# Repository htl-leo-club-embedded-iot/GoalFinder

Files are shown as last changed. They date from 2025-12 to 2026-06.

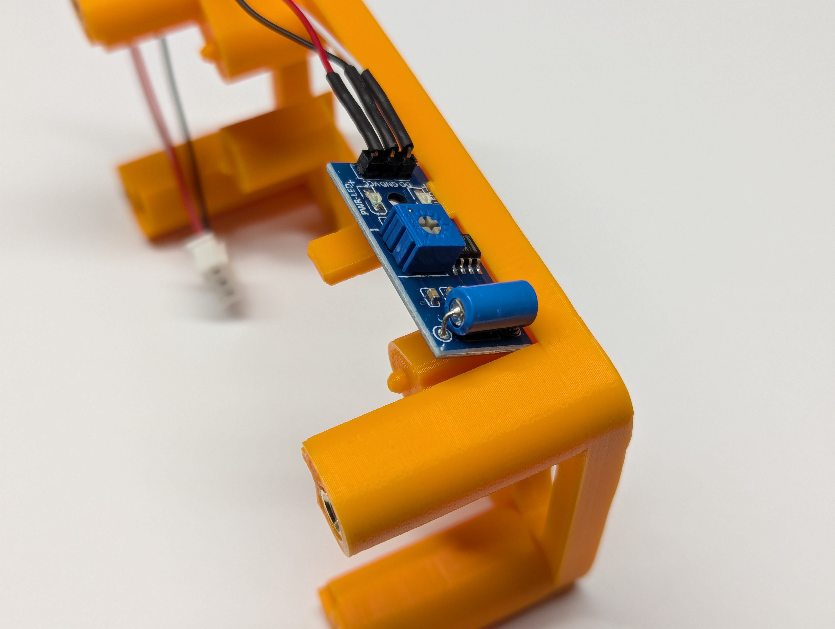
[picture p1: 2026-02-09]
docs/images/fotodoc_assemby/orig/PXL_20251103_211330798.jpg

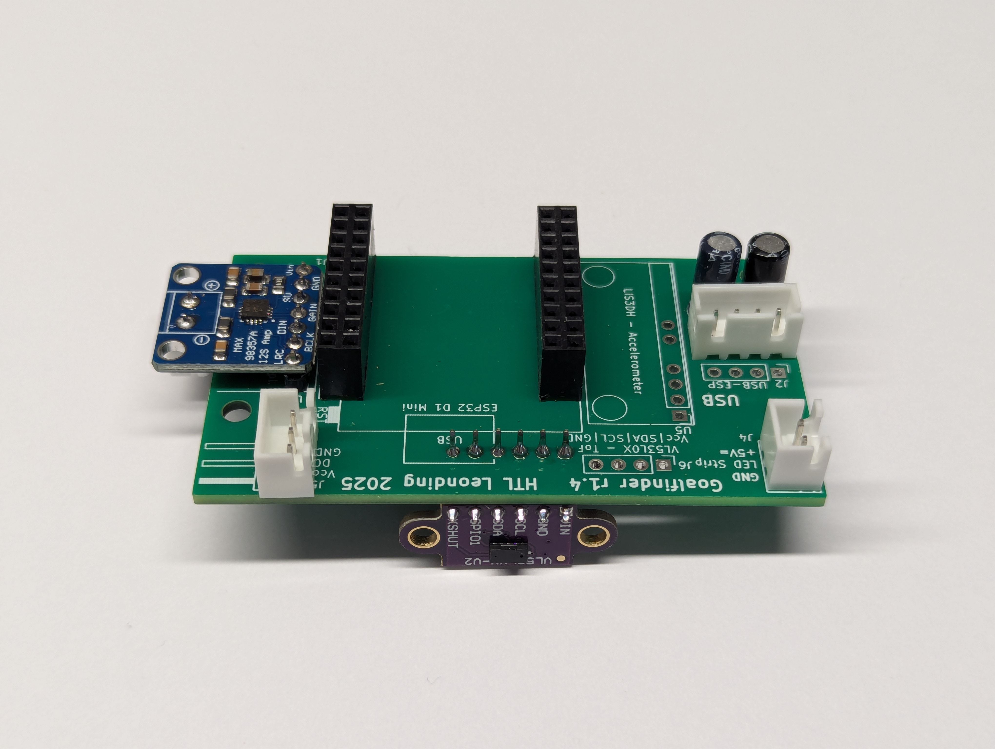
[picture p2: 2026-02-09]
docs/images/fotodoc_assemby/orig/PXL_20251103_104626845.jpg

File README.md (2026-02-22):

# Goalfinder

## About

The GoalFinder device aims to help blind or visually impaired people play basketball by playing a sound to help locate the basket and provides acoustic and visual feedback on hits and misses.
For more information, please visit the [GoalFinder Website](https://goalfinder.github.io)

## Branches

### Main Branches

+ `main` The main branch is used for releases only
+ `development` Is the branch that sees all development work

### Backup Branches

There are still two discontinued branches from before the takeover

+ `pages-alt` Old GitHub Pages branch
+ `multithreading-alt` Old branch focused on adding multithreading to the GoalFinder device

## Website

The GoalFinder website is accessible at [goalfinder.github.io](https://goalfinder.github.io) and is split of into [it's own repository](https://github.com/goalfinder/goalfinder.github.io)

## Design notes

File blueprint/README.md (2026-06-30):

# Blueprint Directory

## Structure
    .
    ├── design          The development section for the GoalFinder device
    │   ├── housing/        The design for the housing
    │   └── pcb/            The design for the PCB
    └── export          To be exported files for production
        ├── 3d-files/       .3mf projects or .gcode (mostly for Creality K1C and K1 Max printers using Hyper-PLA) files for producing the housing
        └── pcb/            Generated production files for producing the PCB

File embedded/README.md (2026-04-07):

# Embedded Directory

## Testing And Coverage

The test setup uses a dedicated host environment (`env:native`) in
`platformio.ini`. Tests are compiled and executed on the CI runner and are
never included in the firmware image built for `wemos_d1_mini32`.

Run tests locally:

```bash
pio test -e native
```

Generate function coverage for project sources:

```bash
gcovr --root . --object-directory .pio/build/native --filter src --filter lib --txt --txt-metric function
```

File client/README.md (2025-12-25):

# Client Directory

## Structure

    .
    ├── .gitignore           Git ignore rules for the client directory
    ├── merge-bin.py         Python script for merging binary files
    ├── platformio.ini       PlatformIO configuration file
    ├── data/                Data files for the firmware
    │   └── web/             Web assets for the firmware
    │       └── assets/      CSS files for web views
    │           ├── GamesView.css
    │           ├── GeneralSettingsView.css
    │           └── NotFoundView.css
    ├── lib/                Libraries used in the firmware
    │   ├── file_system/    File system management library
    │   │   ├── FileSystem.cpp
    │   │   └── FileSystem.h
    │   ├── lib_audioplayer/    Audio player library
    │   │   ├── library.json
    │   │   ├── include/
    │   │   │   └── AudioPlayer.h
    │   │   └── src/
    │   │       └── AudioPlayer.cpp
    │   ├── lib_bluetoothmanager/   Bluetooth manager library
    │   │   ├── library.json
    │   │   ├── include/
    │   │   │   └── BluetoothManager.h
    │   │   └── src/
    │   │       └── BluetoothManager.cpp
    │   ├── lib_settings/    # Settings management library
    │   │   ├── hal_selector.py
    │   │   ├── library.json
    │   │   ├── include/
    │   │   │   └── system/
    │   │   │       └── Settings.h
    │   │   └── src/
    │   │       └── hal/
    │   │           └── system/
    │   │               ├── dummy/
    │   │               │   └── DummySettings.cpp
    │   │               ├── esp32/
    │   │               │   └── Esp32Settings.cpp
    │   │               └── esp8266/
    │   │                   └── Esp8266Settings.cpp
    │   ├── lib_tofsensor/   Time-of-flight sensor library
    │   │   ├── library.json
    │   │   ├── include/
    │   │   │   └── ToFSensor.h
    │   │   └── src/
    │   │       └── ToFSensor.cpp
    │   └── lib_vibrationsensor/    Vibration sensor library
    │       ├── library.json
    │       ├── include/
    │       │   └── VibrationSensor.h
    │       └── src/
    │           └── VibrationSensor.cpp
    ├── src/    Main application source code
    │   ├── GoalfinderApp.cpp
    │   ├── GoalfinderApp.h
    │   ├── LedController.cpp
    │   ├── LedController.h
    │   ├── LedMode.h
    │   ├── main.cpp    Entry point of the firmware
    │   ├── Settings.cpp
    │   ├── Settings.h
    │   ├── Singleton.h
    │   └── web/             # Web-related source code
    │       ├── SNTP.cpp
    │       ├── SNTP.h
    │       ├── SoftwareUpdater.cpp
    │       ├── SoftwareUpdater.h
    │       ├── WebServer.cpp
    │       ├── WebServer.h
    │       ├── WifiManager.cpp
    │       └── WifiManager.h

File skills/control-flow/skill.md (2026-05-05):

---
name: Control Flow
---

# Control Flow Skill

## Core Philosophy

**Goal**: Ensure execution flow is predictable, testable, and deterministic. Restrict patterns that make reasoning about code behavior difficult.

## Return Statement Rules

### Mandatory Constraints

- **Functions returning values MUST have exactly ONE return statement**
- **Early returns are strictly forbidden**
- **Void functions MUST NOT use any return statement**

### Rationale

Single return points make code behavior predictable and testable:
- Easier to trace execution paths
- Simpler to add cleanup logic
- Better support for debugging and profiling
- Follows principles used in safety-critical systems

### Examples

**Standard - Single Return Pattern:**

```typescript
function validateUser(user: User): boolean {
  let isValid = false;
  
  if (user.id && user.email && user.role) {
    if (user.email.includes('@')) {
      isValid = true;
    }
  }
  
  return isValid;
}
```

**Standard - Void Function (No Return):**

```cpp
void logEvent(const Event& event) {
  if (isEnabled()) {
    Logger::write(event.toString());
  }
}
```

## Loop and Flow Restrictions

### Forbidden Constructs

- **`goto` is strictly forbidden** - Unconditional jumps make code flow unpredictable
- **`break` outside `switch` statements is forbidden** - Use flags or restructure loops instead
- **`continue` should be avoided** - Restructure logic instead; only use with explicit justification in comments

### Rationale

These constructs create non-local jumps in execution flow that:
- Make it difficult to reason about code behavior
- Complicate static analysis and testing
- Can obscure resource cleanup paths
- Violate structured programming principles

### Examples

**Standard - Loop with Flag Variable:**

```cpp
size_t foundIndex = -1;
bool found = false;

for (size_t i = 0; i < data.size() && !found; ++i) {
  if (data[i] == target) {
    foundIndex = i;
    found = true;
  }
}
```

**Standard - Inverted Logic:**

```typescript
for (let user of users) {
  if (user.active) {
    processUser(user);
  }
}
```

## Preferred Control Flow Structure

### Linear, Sequential Logic

Structure code in clear, sequential blocks that flow from top to bottom:

```typescript
function processConnection(config: Config): Result {
  let result: Result = { success: false };
  
  // Step 1: Validate input
  const isValidConfig = validateConfig(config);
  
  // Step 2: Establish connection
  let connection: Connection | null = null;
  if (isValidConfig) {
    connection = establishConnection(config);
  }
  
  // Step 3: Perform operations
  let operationSuccess = false;
  if (connection !== null) {
    operationSuccess = performOperations(connection);
  }
  
  // Step 4: Cleanup and prepare result
  if (connection !== null) {
    closeConnection(connection);
  }
  
  result.success = isValidConfig && operationSuccess;
  
  return result;
}
```

### State-Based Flow (When Appropriate)

Use state variables and state machines for complex flows:

```cpp
enum class ConnectionState {
  IDLE,
  CONNECTING,
  CONNECTED,
  ERROR,
  CLOSED
};

class Connection {
private:
  ConnectionState _state = ConnectionState::IDLE;
  
public:
  void handleEvent(const Event& event) {
    switch (_state) {
      case ConnectionState::IDLE:
        if (event.type == EventType::CONNECT) {
          _state = ConnectionState::CONNECTING;
        }
        break;
      case ConnectionState::CONNECTING:
        if (event.type == EventType::SUCCESS) {
          _state = ConnectionState::CONNECTED;
        } else if (event.type == EventType::FAILURE) {
          _state = ConnectionState::ERROR;
        }
        break;
      // ... other states
    }
  }
};
```

### Switch Statements

Switch statements are acceptable for handling discrete options:

```typescript
function handleMessage(type: MessageType, data: any) {
  switch (type) {
    case MessageType.CONNECT:
      establishConnection(data);
      break;
    case MessageType.DISCONNECT:
      closeConnection();
      break;
    case MessageType.DATA:
      processData(data);
      break;
    default:
      logUnknownMessage(type);
  }
}
```

## Mandatory Exceptions

### Break in Switch Statements

`break` is **required** in switch statements to prevent fall-through:

```typescript
switch (event) {
  case 'click':
    handleClick();
    break;
  case 'hover':
    handleHover();
    break;
}
```

## Benefits of These Rules

✓ **Testability**: Single execution paths are easier to test  
✓ **Debugging**: Call stacks are predictable and traceable  
✓ **Maintainability**: Code changes have localized impact  
✓ **Performance**: No unpredictable jumps affecting branch prediction  
✓ **Safety**: Follows practices from safety-critical system standards  
✓ **Clarity**: Control flow is immediately obvious on code review  

## Review Checklist

When reviewing control flow compliance:

- [ ] No early returns in non-void functions
- [ ] No `goto` statements
- [ ] No `break` outside switch statements
- [ ] `continue` is justified (if present) with a comment
- [ ] Void functions do not have unnecessary returns
- [ ] Execution flow is linear and predictable
- [ ] State machines used where appropriate for complex logic
- [ ] Loop exit conditions are clear
- [ ] Exception handling (if used) doesn't create hidden control flow

## Migration Guide

If working with legacy code that violates these rules, prioritize refactoring:

1. **High priority**: Remove all `goto` statements
2. **High priority**: Consolidate multiple return statements
3. **Medium priority**: Replace `break` in loops with state flags
4. **Medium priority**: Restructure `continue` patterns
5. **Low priority**: Clean up other control flow patterns

Document exceptions in code review comments and create follow-up tasks for refactoring.

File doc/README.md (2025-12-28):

# Documentation

This directory contains the GoalFinder project's technical documentation and contribution guidance.

## Project structure

    ..
    ├── github              GitHub workflows for CI/CD
    ├── .vscode             Configuration files for Visual Studio Code
    ├── assets              Assets for development and documentation
    ├── blueprint           Hardware design files, including 3D models and PCB layouts
    ├── client              Software for the Goalfinder Board, including firmware
    ├── doc-alt             Documentation from the previous repository
    ├── .gitignore          Files and directories excluded from git source control
    ├── LICENSE             Licensing information for the project
    ├── package-lock.json   Locked npm dependencies for consistent builds
    └── README.md           Description of the repository

## Contribute

See the [contribution guide](./contribute/README.md) for detailed instructions on how to use the provided development tools.

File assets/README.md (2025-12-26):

# Assets Directory

## Structure
    .
    ├── audio               Audio files
    │   ├── beep                Beep Sounds
    │   ├── goal                Goal sounds
    │   ├── metronome           Metronome Sounds
    │   ├── miss                Miss sounds
    │   └── success             Success sounds
    └── img                 Image files
        └── logo                Logos

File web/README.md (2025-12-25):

# Web Directory

This template should help get you started developing with Vue 3 in Vite.

## Recommended IDE Setup

[VSCode](https://code.visualstudio.com/) + [Volar](https://marketplace.visualstudio.com/items?itemName=Vue.volar) (and disable Vetur).

## Type Support for `.vue` Imports in TS

TypeScript cannot handle type information for `.vue` imports by default, so we replace the `tsc` CLI with `vue-tsc` for type checking. In editors, we need [Volar](https://marketplace.visualstudio.com/items?itemName=Vue.volar) to make the TypeScript language service aware of `.vue` types.

## Customize configuration

See [Vite Configuration Reference](https://vite.dev/config/).

## Project Setup

```sh
npm install
```

### Compile and Hot-Reload for Development

```sh
npm run dev
```

### Type-Check, Compile and Minify for Production

```sh
npm run build
```

## Structure

    .
    ├── .gitignore           # Git ignore rules for the web directory
    ├── env.d.ts             # TypeScript environment variable definitions
    ├── index.html           # Entry point for the web application
    ├── package.json         # npm configuration file for managing dependencies
    ├── README.md            # Documentation for the web directory
    ├── tsconfig.app.json    # TypeScript configuration for the application
    ├── tsconfig.json        # Base TypeScript configuration
    ├── tsconfig.node.json   # TypeScript configuration for Node.js scripts
    ├── vite.config.ts       # Vite configuration file for development and build
    ├── src/                 # Source code for the web application
    │   ├── App.vue          # Root Vue component
    │   ├── main.ts          # Entry point for the application
    │   ├── assets/          # Static assets such as styles and images
    │   │   ├── main.css     # Global CSS styles
    │   │   └── logos/       # Logo images
    │   ├── components/      # Reusable Vue components
    │   │   ├── BluetoothManager.vue
    │   │   ├── Button.vue
    │   │   ├── Card.vue
    │   │   ├── IconButton.vue
    │   │   ├── InputForm.vue
    │   │   ├── LaserSensorManager.vue
    │   │   ├── LedManager.vue
    │   │   ├── Modal.vue
    │   │   ├── NavigationBar.vue
    │   │   ├── Page.vue
    │   │   ├── SoftwareUpdateModal.vue
    │   │   ├── ToggleButton.vue
    │   │   ├── VibratiosensorManager.vue
    │   │   └── VolumeManager.vue
    │   │   └── icons/       # Icon components
    │   │       ├── AddIcon.vue
    │   │       ├── BluetoothIcon.vue
    │   │       ├── GearIcon.vue
    │   │       ├── InfoCircleIcon.vue
    │   │       ├── LightbulbIcon.vue
    │   │       ├── MinusIcon.vue
    │   │       ├── PlayIcon.vue
    │   │       ├── PowerIcon.vue
    │   │       ├── TrashIcon.vue
    │   │       ├── UpdateIcon.vue
    │   │       ├── VolumeUpIcon.vue
    │   │       └── WifiOffIcon.vue
    │   ├── models/          # TypeScript models for data structures
    │   │   ├── game.ts
    │   │   ├── player.ts
    │   │   └── team.ts
    │   ├── router/          # Vue Router configuration
    │   │   └── index.ts
    │   ├── stores/          # Pinia stores for state management
    │   │   ├── games.ts
    │   │   └── settings.ts
    │   └── views/           # Vue components for application views
    │       ├── AboutView.vue
    │       ├── HomeView.vue
    │       ├── NotFoundView.vue
    │       ├── Games/       # Game-related views
    │       │   ├── GamesView.vue
    │       │   ├── ShotChallengeView.vue
    │       │   └── TimedShotsChallengeView.vue
    │       └── Settings/    # Settings-related views
    │           ├── AudioSettingsView.vue
    │           ├── DevicesSettingsView.vue
    │           ├── SettingsView.vue
    │           └── SystemSettingsView.vue

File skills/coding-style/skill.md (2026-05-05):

---
name: Coding Style
--- 

# Coding Style Skill

## Core Principles

- **Minimal implementations**: Favor simplicity and directness over clever constructs
- **Code reuse**: Leverage existing infrastructure whenever possible
- **Avoid duplication**: Unnecessary abstraction should be eliminated
- **Prioritize readability**: Never sacrifice clarity for brevity

## Naming Conventions

### General Rules

- Use clear and meaningful variable names that self-document their purpose
- Avoid cryptic abbreviations unless they are widely understood in the specific context
- Names should reflect intent and domain terminology

### Language-Specific Conventions

#### TypeScript / JavaScript

- **Constants**: `UPPER_SNAKE_CASE` (e.g., `MAX_RETRIES`)
- **Variables & Functions**: `camelCase` (e.g., `connectionStatus`, `handleClick()`)
- **Classes & Interfaces**: `PascalCase` (e.g., `ConnectionManager`, `ISettings`)
- **Private members**: Prefix with underscore `_privateMethod()`
- **Vue components**: `PascalCase` with `.vue` extension (e.g., `ConnectionSettingsView.vue`)

#### C++

- **Constants & Macros**: `UPPER_SNAKE_CASE` (e.g., `MAX_BUFFER_SIZE`)
- **Functions**: `camelCase` or `PascalCase` depending on context (e.g., `handleEvent()`, `ProcessData()`)
- **Classes**: `PascalCase` (e.g., `LedController`)
- **Member variables**: Prefix with underscore `_memberVar`
- **Private methods**: Prefix with underscore `_privateMethod()`

## Code Structure

### Function Organization

- **Keep functions small and focused**: Each function should have a single, clear responsibility
- **Single level of abstraction**: Functions should operate at one conceptual level
- **Prefer straightforward logic**: Avoid clever or complex constructs that reduce readability

### File Organization

- **Group related functionality**: Keep related code in the same file or module
- **Logical ordering**: Define utilities before usage, public interfaces before implementations
- **Clear separation of concerns**: Different concerns should be in different files

## Line Length & Formatting

- **Target line length**: 100 characters maximum
- **Respect language conventions**: Follow language-specific style guides (Prettier for TS/JS, clang-format for C++)
- **Indentation**: Use consistent indentation (2 spaces for YAML/JSON, 4 spaces for code)

## Import Organization

### TypeScript/JavaScript

```typescript
// 1. External libraries
import Vue from 'vue'
import axios from 'axios'

// 2. Internal absolute imports
import { useStore } from '@/stores'
import { Logger } from '@/utils'

// 3. Relative imports
import { helper } from './helpers'
```

### C++

```cpp
// 1. System headers
#include <iostream>
#include <vector>

// 2. Library headers
#include <Arduino.h>

// 3. Local headers
#include "Config.h"
#include "LedController.h"
```

## Type Safety

- **Use types meaningfully**: Leverage language type systems to prevent errors
- **Avoid `any` in TypeScript**: Use proper typing; use `unknown` only when truly necessary
- **Be explicit**: Don't rely on implicit conversions

## Common Patterns

### Error Handling

- Use exceptions or result types consistently across the codebase
- Document error conditions in function documentation
- Avoid silent failures

### State Management

- Minimize mutable state
- Make state changes explicit and predictable
- Document state transitions when non-obvious

### Performance Considerations

- Write readable code first; optimize only where profiling shows bottlenecks
- Document performance-critical sections with explanatory comments
- Include benchmarks for critical paths if performance is important

## Review Checklist

When reviewing code for style compliance:

- [ ] Names clearly express intent
- [ ] Functions have single responsibility
- [ ] No unnecessary duplication
- [ ] Code is readable without extensive comments
- [ ] Language conventions are followed
- [ ] Import order is correct
- [ ] No overly complex control flow

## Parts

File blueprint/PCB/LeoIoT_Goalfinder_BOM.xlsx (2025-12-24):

Reference | Value | Footprint | Qty | Beschreibung | Comment / Supplier
C1 | 22µF | Capacitor_THT:CP_Radial_D5.0mm_P2.00mm | 1 | Polarized capacitor, small symbol
C2 | 4,7µF | Capacitor_THT:CP_Radial_D5.0mm_P2.00mm | 1 | Unpolarized capacitor, small symbol
C3 | 0,1µF | Capacitor_THT:C_Rect_L13.0mm_W4.0mm_P10.00mm_FKS3_FKP3_MKS4 | 1 | Unpolarized capacitor, small symbol
C4,C5,C6,C7,C8 | 100nF | Capacitor_SMD:C_0805_2012Metric_Pad1.18x1.45mm_HandSolder | 5 | Unpolarized capacitor, small symbol
Copt4,Copt5,Copt6,Copt7,Copt8 | 100nF | Capacitor_THT:C_Disc_D5.0mm_W2.5mm_P2.50mm | 0 | Unpolarized capacitor, small symbol | Optional for THT parts, replaces C4, C5, C6, C7, C8 https://www.reichelt.de/de/de/shop/produkt/keramik-kondensator_100_nf_-20_80_y5v_50_100_v_rm_5-9265
J2 | LED Strip | Connector_JST_2.54:JST_XH_B2B-XH-A_1x02_P2.54mm_Vertical | 1 | Connector for LED Strip
J1 | USB_B_Micro_Breakout | Breakout_Boards:Micro-USB_BreakoutBoard | 1 | USB Micro Type B connector | https://www.amazon.de/KARELLS-Steckerkabel-Verl%C3%A4ngerungskabel-Stromladekabel-Ersatzkabel/dp/B0D6362W88
D1, J1e1 | Conn_01x02_Pin | 5V LED Strip, max 30W | 1 | LED Strip with connector suitable for J2 | https://www.amazon.de/GOMING-COB-Selbstklebend-Wasserdicht-Lichtband/dp/B09VGR6PWH/ref=sr_1_4?th=1
J3 | GAIN | Connector_PinHeader_2.54mm:PinHeader_2x05_P2.54mm_Vertical | 1 | Jumper bar for gain selection | either wire bridge or:
 |  |  |  |  | Jumper: https://www.reichelt.de/de/de/shop/produkt/kurzschlussbruecke_schw_m_grifflasche-9019
 |  |  |  |  | Pin Header: https://www.reichelt.de/de/de/shop/produkt/stiftleiste_2x20-pol_vergoldet_2_54mm-235664
LS1 | Speaker | Breakout_Boards:Mono-Enclosed_Speaker_70x30x17mm_onboard | 1 | Speaker, 3 W, 8 Ohm | https://www.amazon.de/dp/B09PL6XFHC
Q1 | IRFZ44N | Package_TO_SOT_THT:TO-220-3_Horizontal_TabDown | 1 | FET | https://www.reichelt.de/de/de/shop/produkt/mosfet_n-ch_60v_48a_110w_0_023r_to220ab-257487
R1,R2 | 100k | Resistor_THT:R_Axial_DIN0309_L9.0mm_D3.2mm_P12.70mm_Horizontal | 2 | Resistor
R4 | 1k | Resistor_THT:R_Axial_DIN0309_L9.0mm_D3.2mm_P12.70mm_Horizontal | 1 | Resistor
R5 | 33k | Resistor_THT:R_Axial_DIN0309_L9.0mm_D3.2mm_P12.70mm_Horizontal | 1 | Resistor
U1 | ESP32_D1_mini | ESP32_D1_mini:ESP32_D1_mini | 1 | ESP32 D1 mini from AZ-Delivery | https://www.amazon.de/AZDelivery-Bluetooth-Internet-Entwicklungsboard-kompatibel/dp/B08BTYCGVV
U2 | VL53L0X_Breakout | Breakout_Boards:VL53L0X_Breakout_Board_vertical_flat | 1 | 2m distance ranging ToF sensor, Optical LGA12 | https://www.amazon.de/AZDelivery-VL53L0X-Flight-kompatibel-Arduino/dp/B086TSNTFD
U3 | MAX98357A_Breakout | Breakout_Boards:MAX98357A_Breakout_Board | 1 | Mono DAC with amplifier, I2S, PCM, TDM, 32-bit, 96khz, 3.2W, TQFP-16 | https://www.amazon.de/AZDelivery-filterloses-Breakout-Modul-Decoder-Modul-Anwendungsbereich/dp/B09PL947ZG
U4 | SW420_Breakout | Breakout_Boards:SW420_Breakout_Board_Horizontal | 1 | Vibrationsensor, Shocksensor | https://www.amazon.de/AZDelivery-Vibration-Sch%C3%BCttel-Ersch%C3%BCtterung-Arduino/dp/B07V9CZ89G

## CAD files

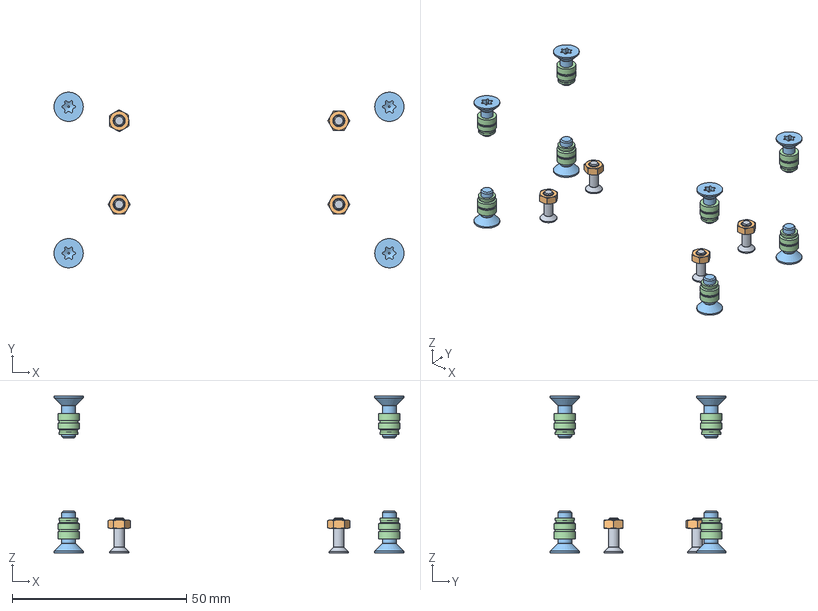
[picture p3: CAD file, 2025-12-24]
blueprint/Housing/LeoIoT-Goalfinder-Assembly_GF1_4_compact.FCStd
100.4 x 50.4 x 45.0 mm
M3x10-Schraube x 4
M3-Mutter x 4
M4x12-Schraube x 8
M4x6-Gewindeeinsatz x 8

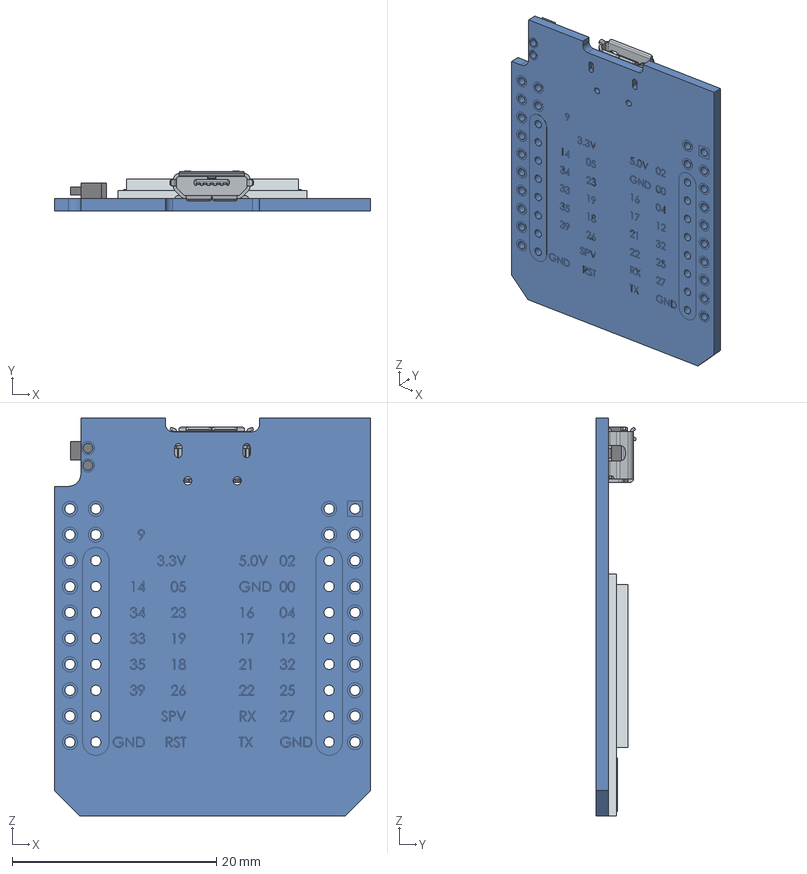
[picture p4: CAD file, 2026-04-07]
assets/3D/pcb/Wemos-Mini-D1-ESP32.STEP
31.0 x 3.92 x 39.0 mm
Wemos-Mini-D1-ESP32
Wemos-Mini-D1-ESP033
Wemos-Mini-D1-ESP034
Wemos-Mini-D1-ESP035

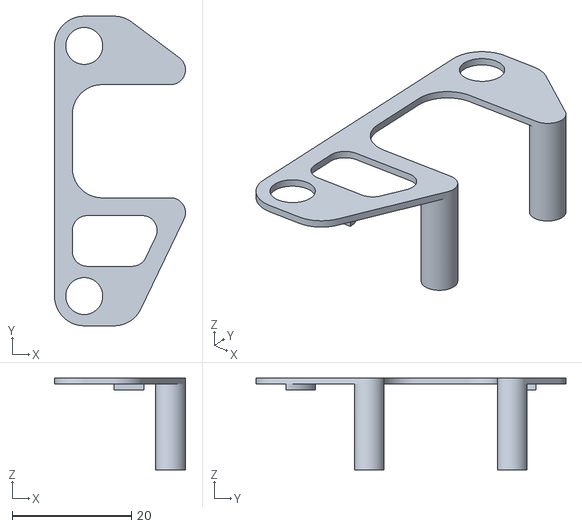
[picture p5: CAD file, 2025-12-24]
blueprint/Housing/3D-Print/bracket-top-left.stl
22.0 x 52.0 x 15.4

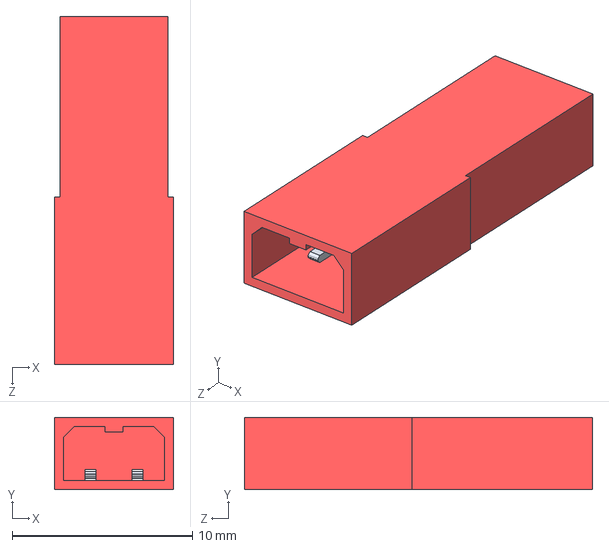
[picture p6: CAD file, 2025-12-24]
blueprint/Housing/JST-SYP_Male.step
6.60 x 4.00 x 19.3 mm

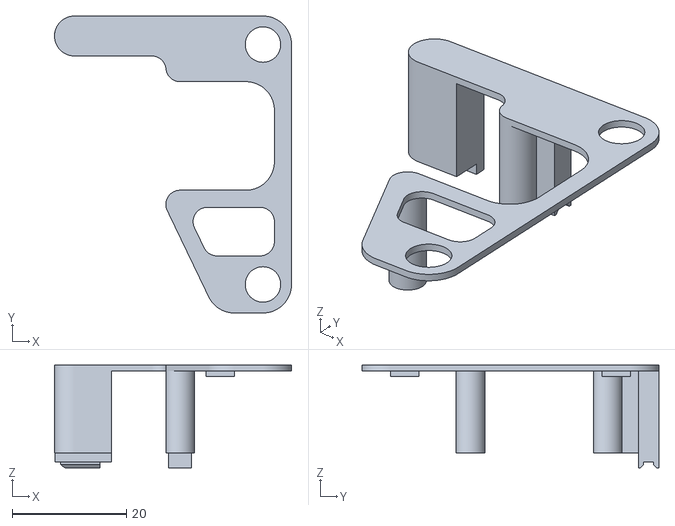
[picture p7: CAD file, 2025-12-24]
blueprint/Housing/3D-Print/bracket-top-right.stl
41.5 x 52.0 x 18.0

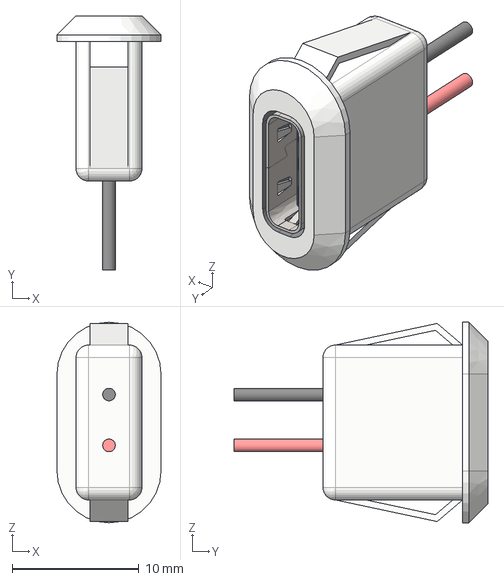
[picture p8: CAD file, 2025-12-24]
blueprint/Housing/USB-C_socket_platemount.step
8.20 x 20.0 x 15.8 mm
USB Connector Type C female

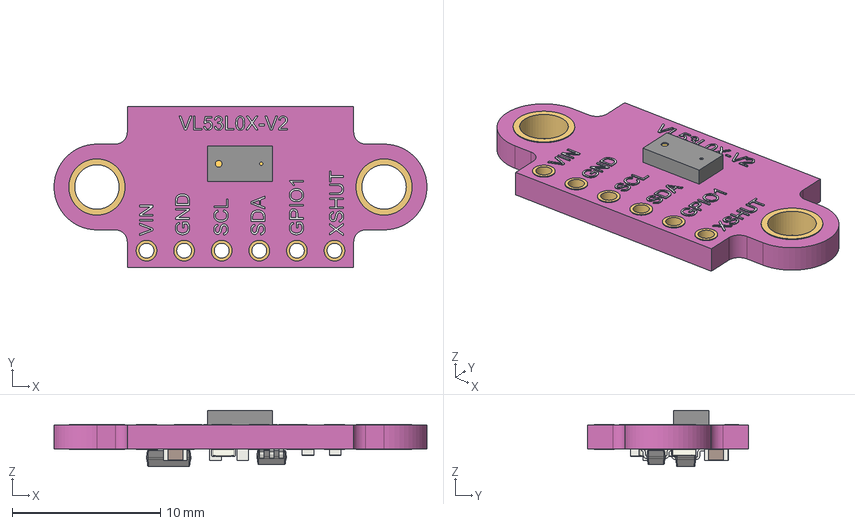
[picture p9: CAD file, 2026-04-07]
assets/3D/pcb/VL53L0X_TOF.step
25.2 x 10.9 x 3.80 mm
PCB_pink
Trou1 x 6
TrouFix01 x 2
Text_VIN
Text_GND
Text_SCL
Text_SDA
Text_GPIO1
Text_XSHUT
Text_VL53L0X-V2
VL53L0X
C_0603_1608Metric
R_Array_Convex_4x0603
SOT_23
C_0603_1608Metric001
C_0603_1608Metric002
R_0603_1608Metric
R_0603_1608Metric001
SOT_363_SC_70_6

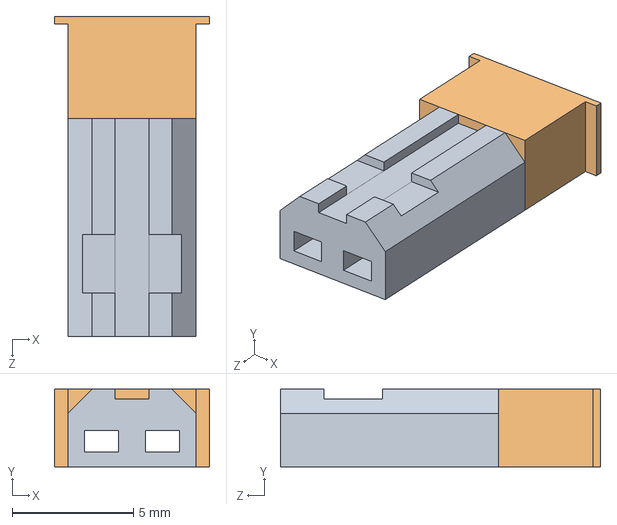
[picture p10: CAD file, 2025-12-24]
blueprint/Housing/JST-SYP_Female.step
6.40 x 3.20 x 13.2 mm

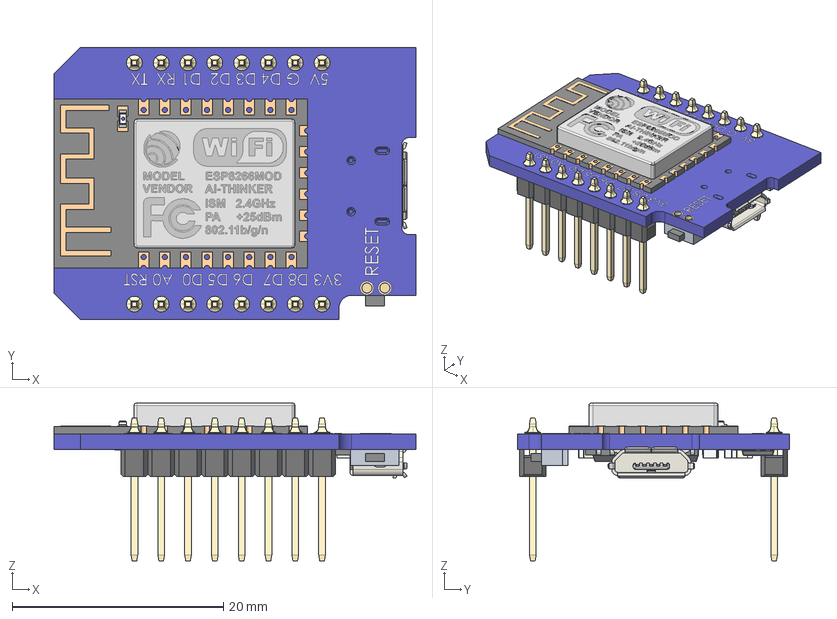
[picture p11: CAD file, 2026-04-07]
assets/3D/pcb/wemos-mini-d1.stp
34.3 x 25.8 x 14.9 mm
PRODUCT_146_ASM_2
PRODUCT_260_3
PRODUCT_323_ASM_2
RES_0805_1 x 12
CAP_0805_1 x 7
SOT23_1_1 x 2
SOT23_2_1 x 2
SOT23_3_1 x 2
SOT23_001_1 x 2
SOT23-5_1
SOT23-5_001_1_1
SOT23-5_001_2_1
SOT23-5_001_3_1
SOT23-5_001_4_1
SOT23-5_001_5_1
SOD-323_1
SOIC-16_150MIL_1
SOIC-16_150MIL_001_1_1
SOIC-16_150MIL_001_2_1
SOIC-16_150MIL_001_3_1
SOIC-16_150MIL_001_4_1
SOIC-16_150MIL_001_5_1
SOIC-16_150MIL_001_6_1
SOIC-16_150MIL_001_7_1
SOIC-16_150MIL_001_8_1
SOIC-16_150MIL_001_9_1
SOIC-16_150MIL_001_10_1
SOIC-16_150MIL_001_11_1
SOIC-16_150MIL_001_12_1
SOIC-16_150MIL_001_13_1
SOIC-16_150MIL_001_14_1
SOIC-16_150MIL_001_15_1
SOIC-16_150MIL_001_16_1
COMPONENTS_2_11__2
_PUSH_BUTTON_-_IMPORTIERT1__2
_USB_SOCKET_-_IMPORTIERT1__2
PCB_2
PIN x 16

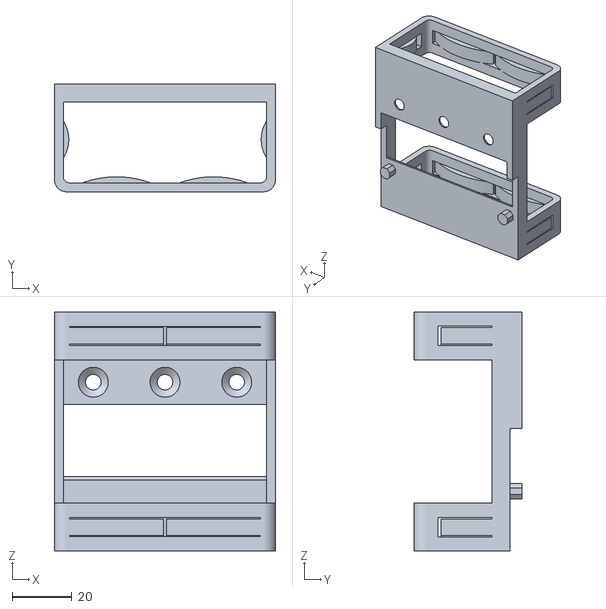
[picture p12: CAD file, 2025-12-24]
blueprint/Housing/Powerbank-Holder_Anker.stl
74.0 x 36.0 x 80.0

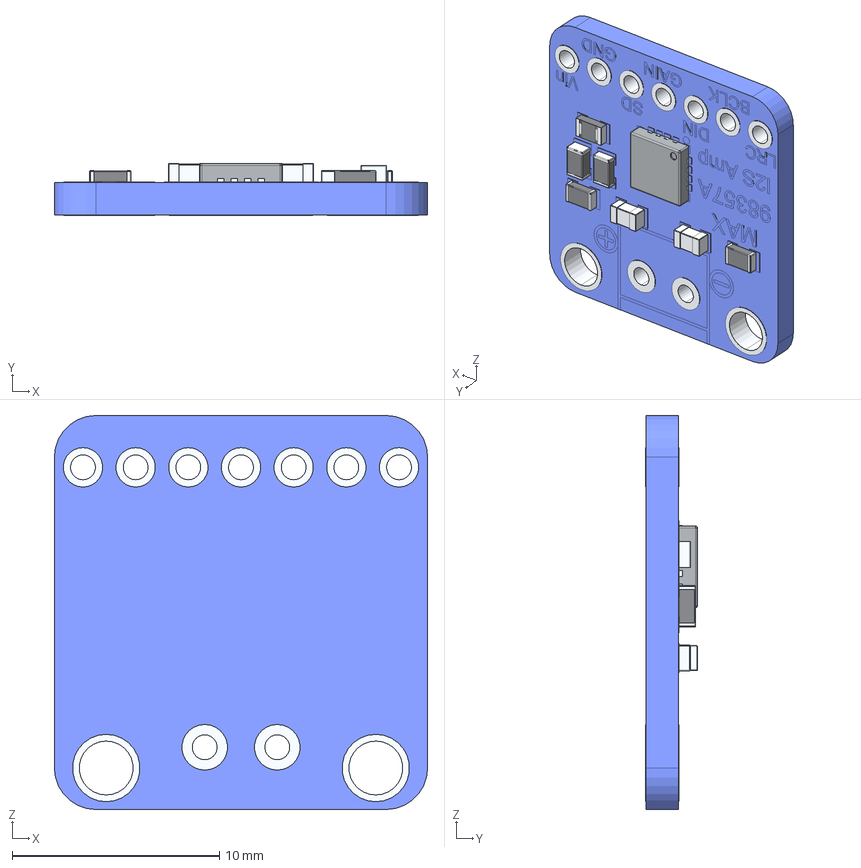
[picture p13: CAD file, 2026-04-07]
assets/3D/pcb/MAX98357A_I2S.STEP
18.0 x 2.50 x 19.0 mm
MAX98357A_I2S006
MAX98357A_I2S007
MAX98357A_I2S008
MAX98357A_I2S009
MAX98357A_I2S010
MAX98357A_I2S011
MAX98357A_I2S012
MAX98357A_I2S013
MAX98357A_I2S014
MAX98357A_I2S015
MAX98357A_I2S016
MAX98357A_I2S017
MAX98357A_I2S018
MAX98357A_I2S019
MAX98357A_I2S020
MAX98357A_I2S021
MAX98357A_I2S022
MAX98357A_I2S023
MAX98357A_I2S024
MAX98357A_I2S025
MAX98357A_I2S026
MAX98357A_I2S027
MAX98357A_I2S028
MAX98357A_I2S029
MAX98357A_I2S030
MAX98357A_I2S031
MAX98357A_I2S032
MAX98357A_I2S033
MAX98357A_I2S034
MAX98357A_I2S035
MAX98357A_I2S036
MAX98357A_I2S037
MAX98357A_I2S038
MAX98357A_I2S039
MAX98357A_I2S040
MAX98357A_I2S041
MAX98357A_I2S042
MAX98357A_I2S049
MAX98357A_I2S050
MAX98357A_I2S058
MAX98357A_I2S071
MAX98357A_I2S074
MAX98357A_I2S076
MAX98357A_I2S078
MAX98357A_I2S086
MAX98357A_I2S107
MAX98357A_I2S110
MAX98357A_I2S119
MAX98357A_I2S120
MAX98357A_I2S121

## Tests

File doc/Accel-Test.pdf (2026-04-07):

# Idle Testing

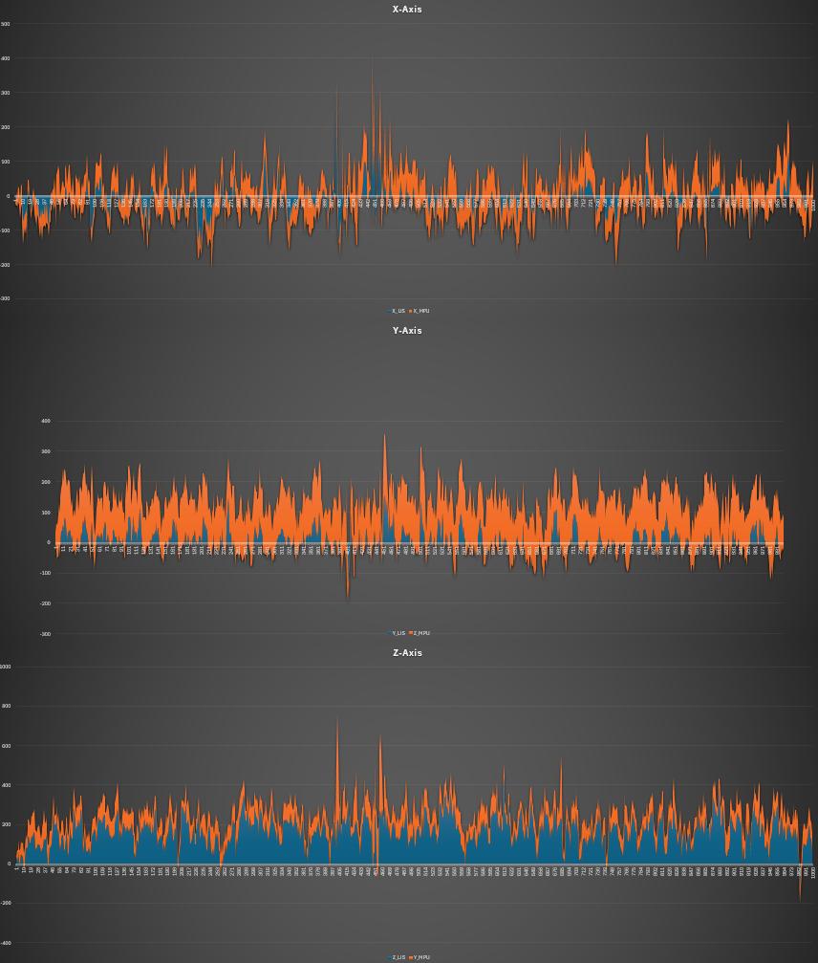
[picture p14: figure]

## █ LIS3DHS

## █ MPU6050

# Shake Testing

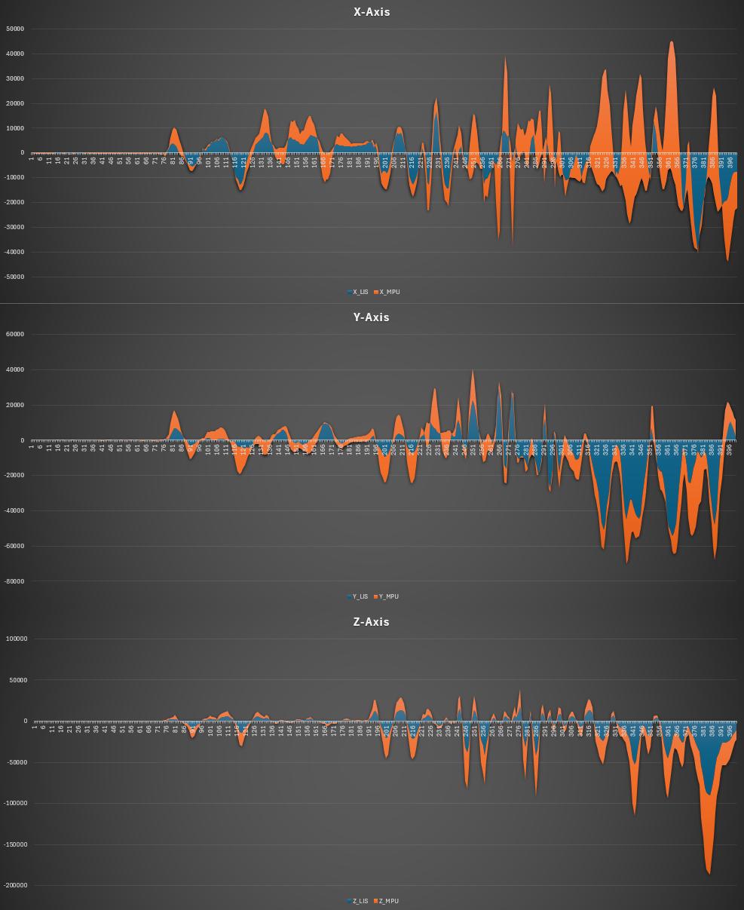
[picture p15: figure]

## █ LIS3DHS

## █ MPU6050

# Shot Detection Testing

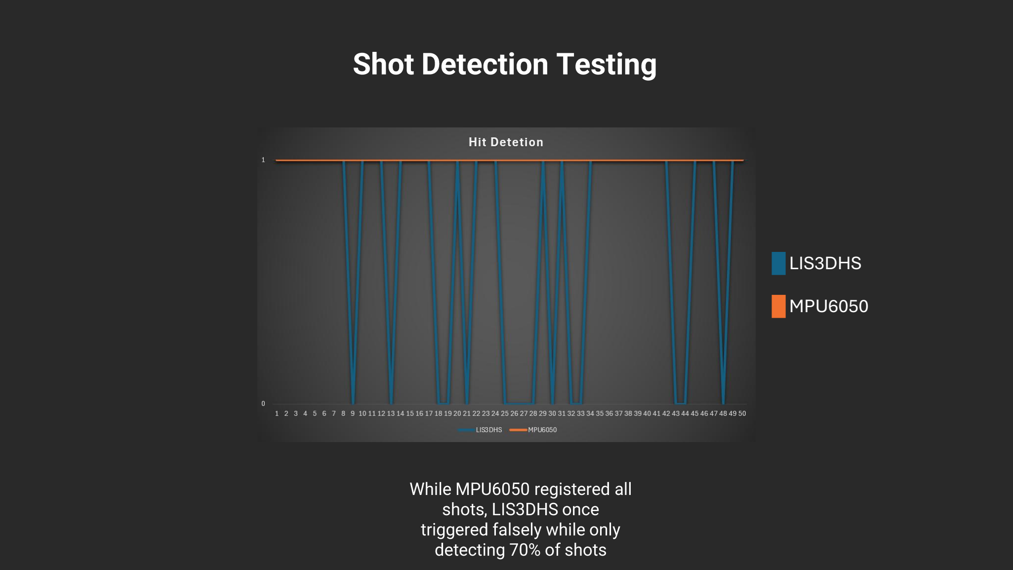
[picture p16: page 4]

## █ LIS3DHS

## █ MPU6050

While MPU6050 registered all shots , LIS3DHS once
triggered falsely while only detecting 70% of shots

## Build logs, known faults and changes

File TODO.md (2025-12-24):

 - Rework entire firmware to run on `esp-idf` framework
 - Create documentation based on existing `.md` files and experiences. Also expand it and build it out. Implement translation for MarkDown Doc

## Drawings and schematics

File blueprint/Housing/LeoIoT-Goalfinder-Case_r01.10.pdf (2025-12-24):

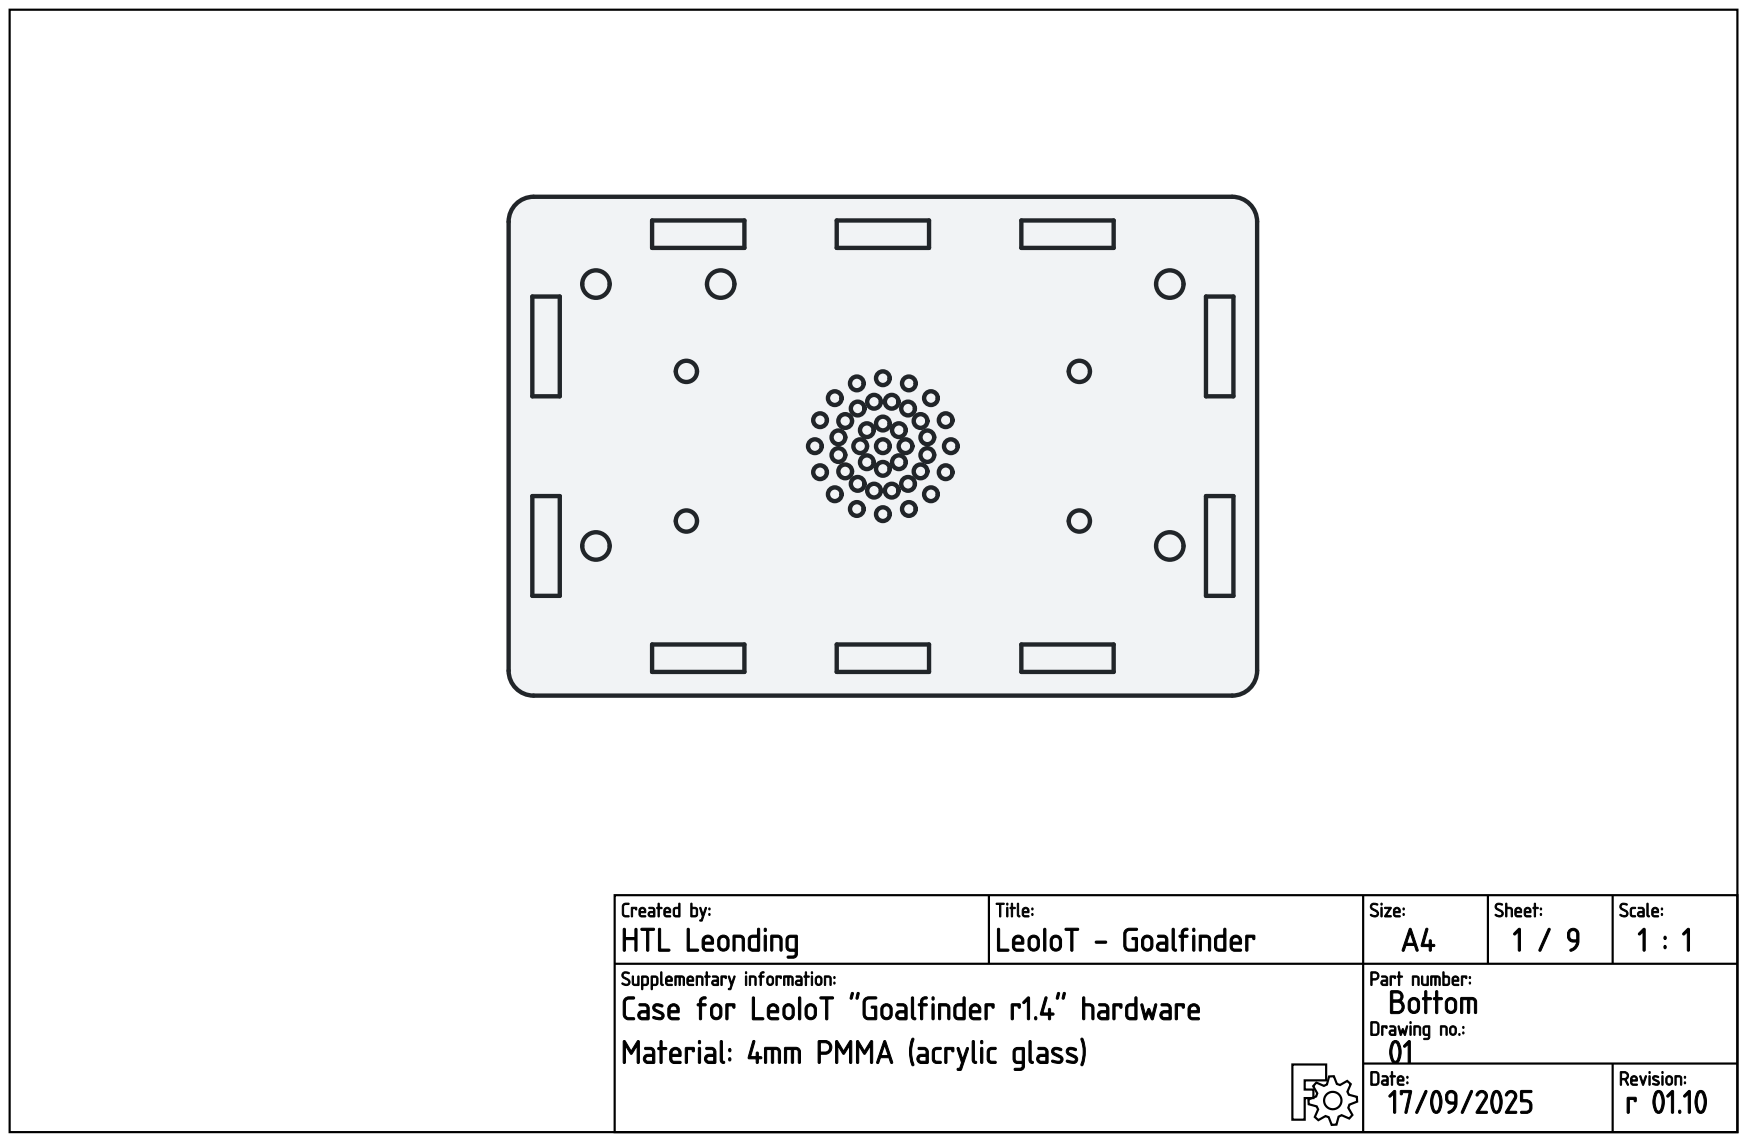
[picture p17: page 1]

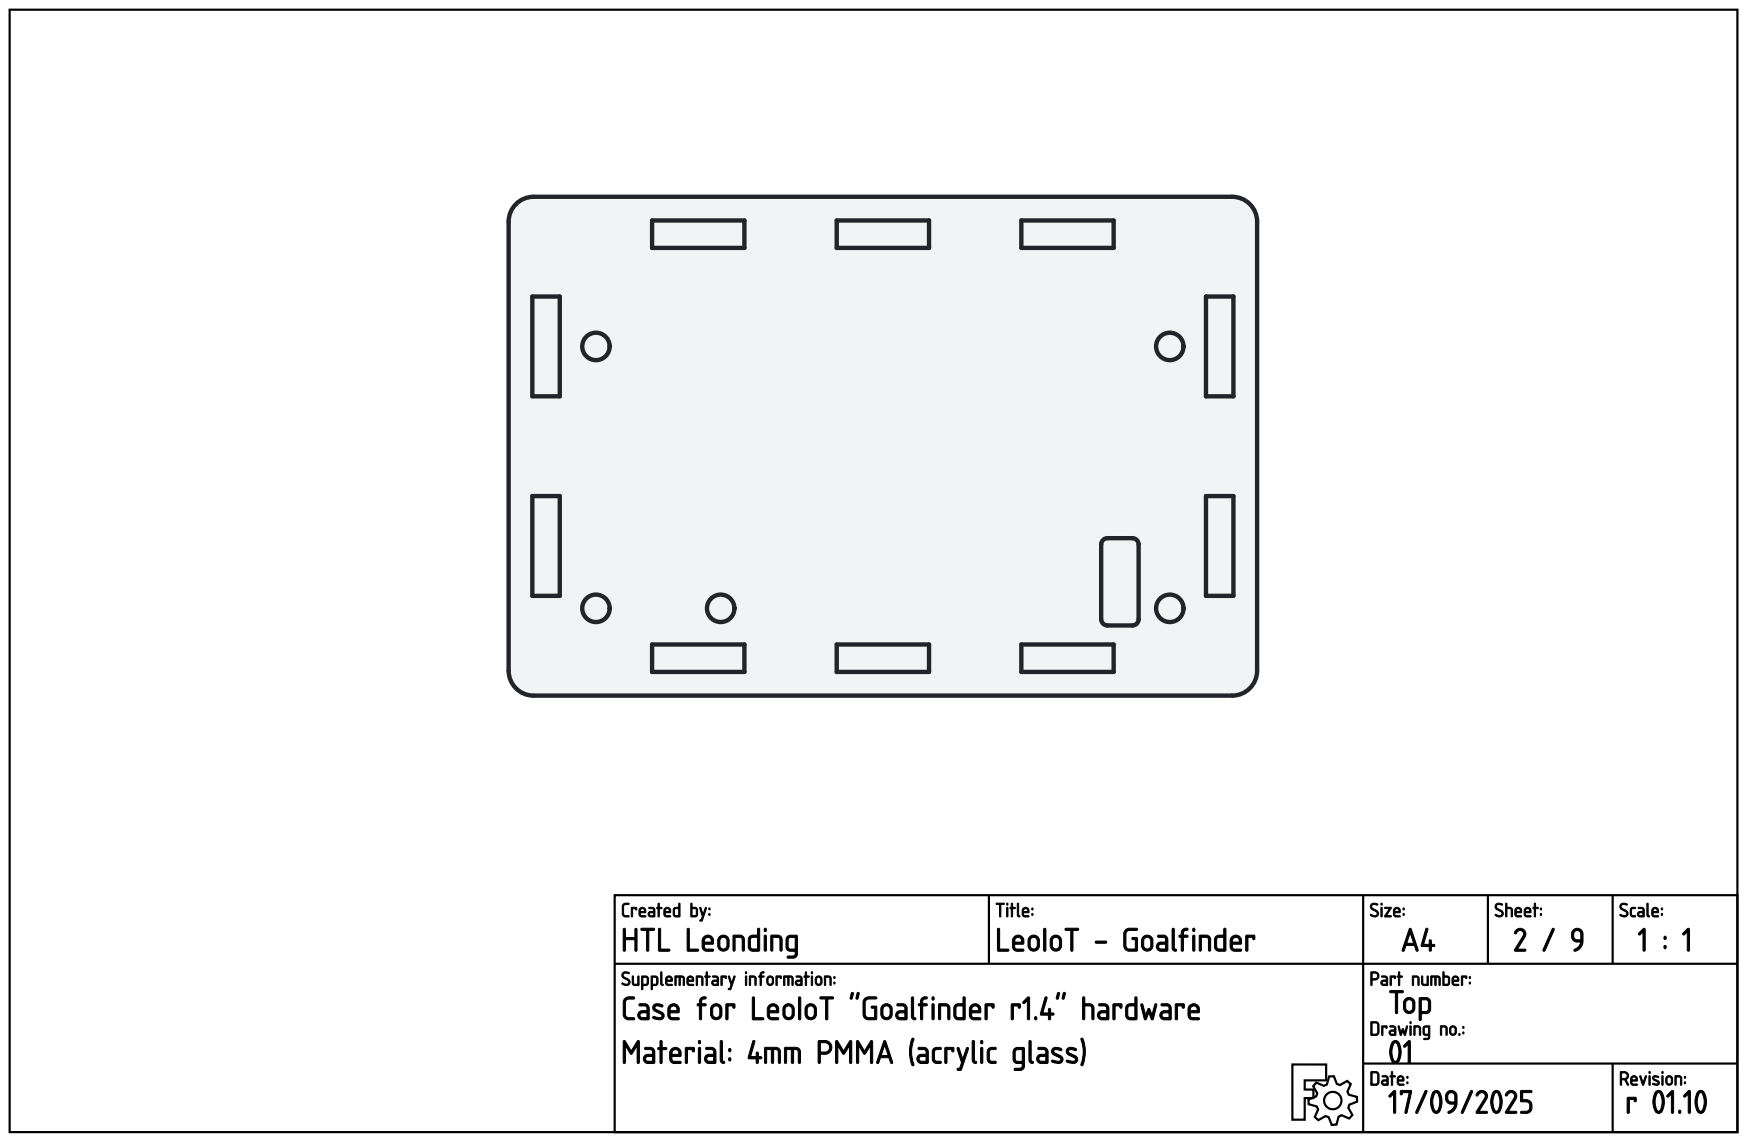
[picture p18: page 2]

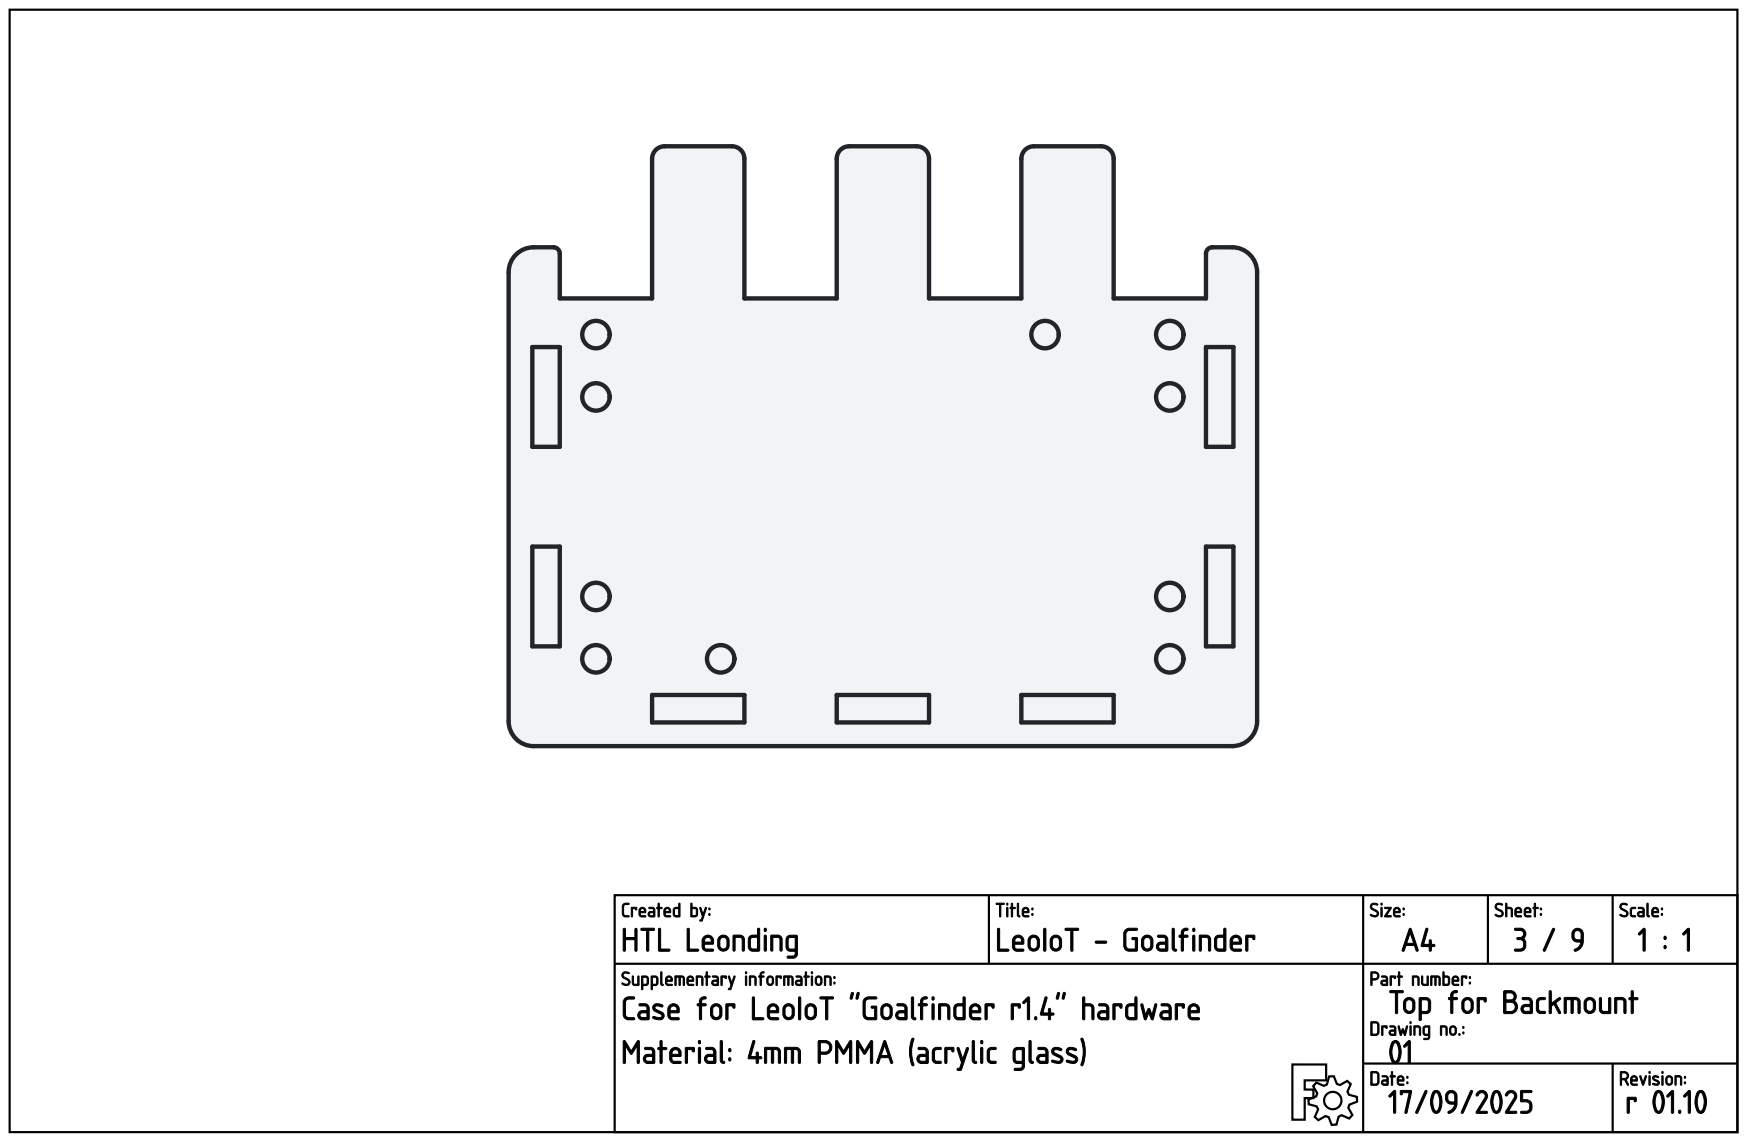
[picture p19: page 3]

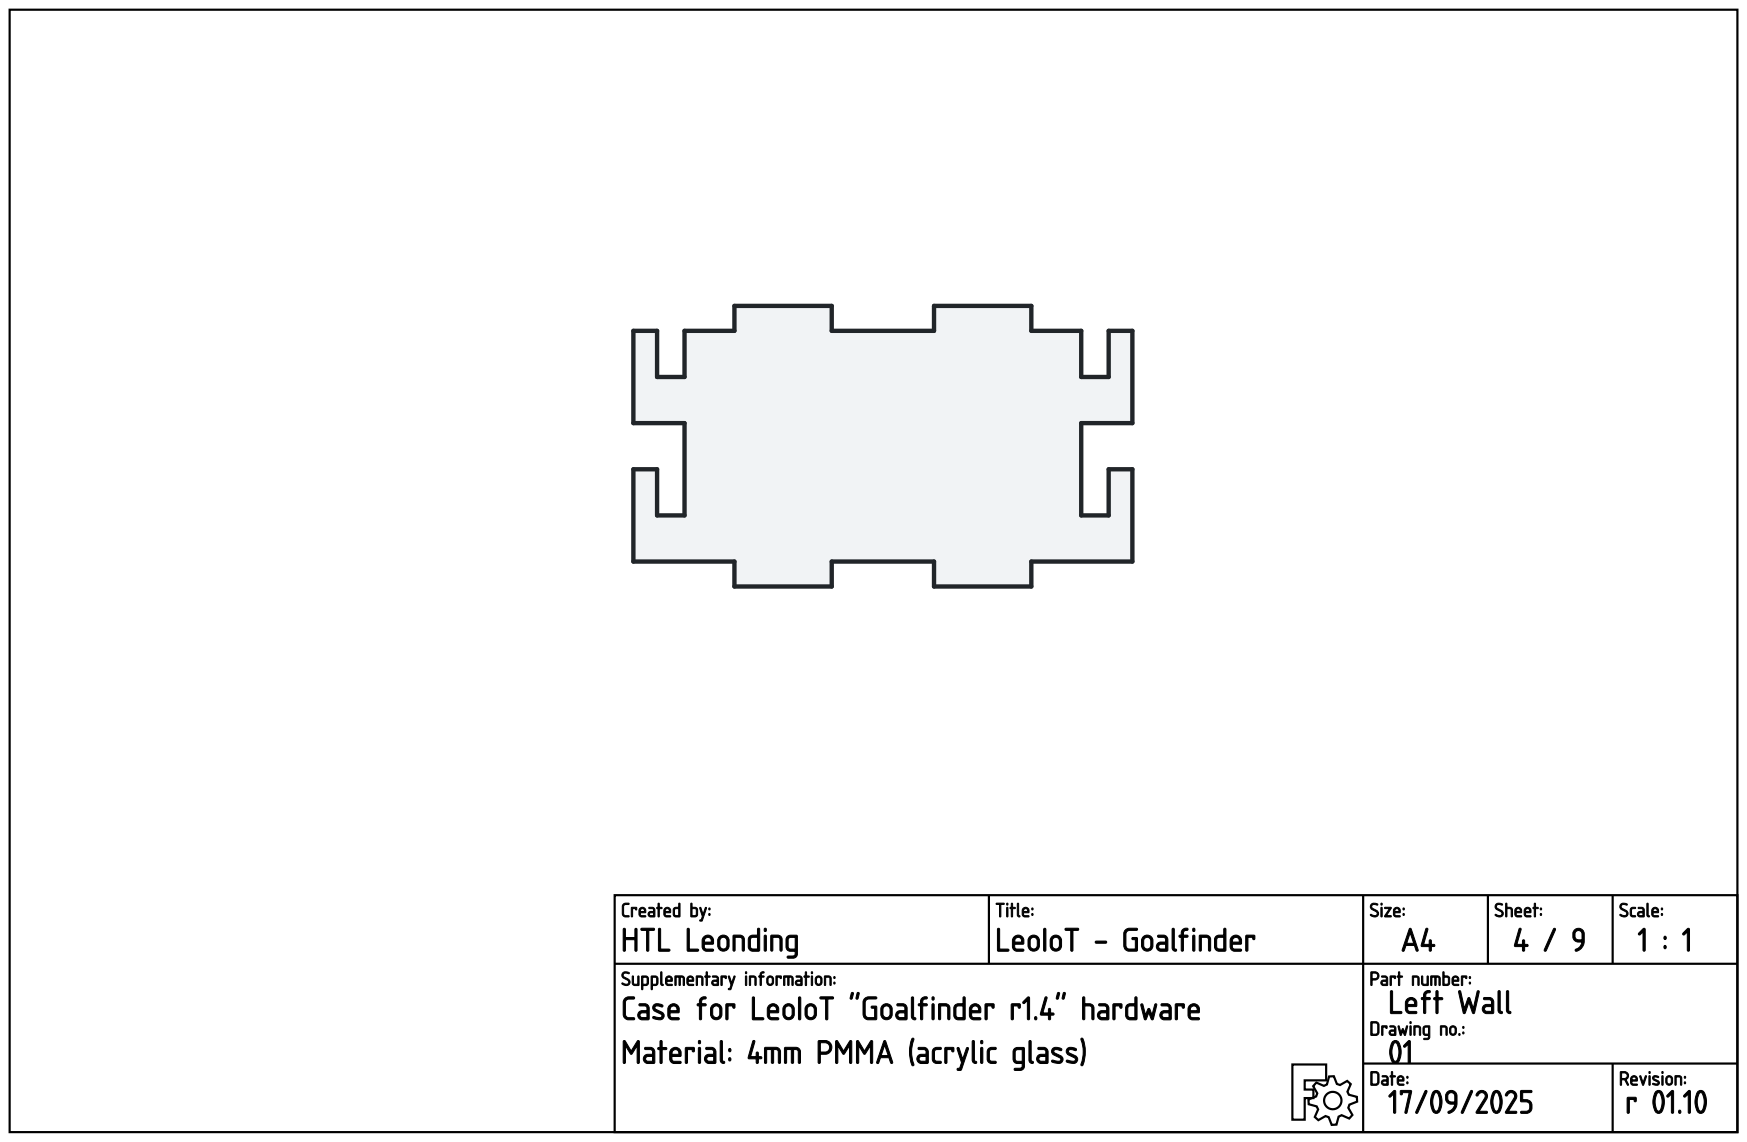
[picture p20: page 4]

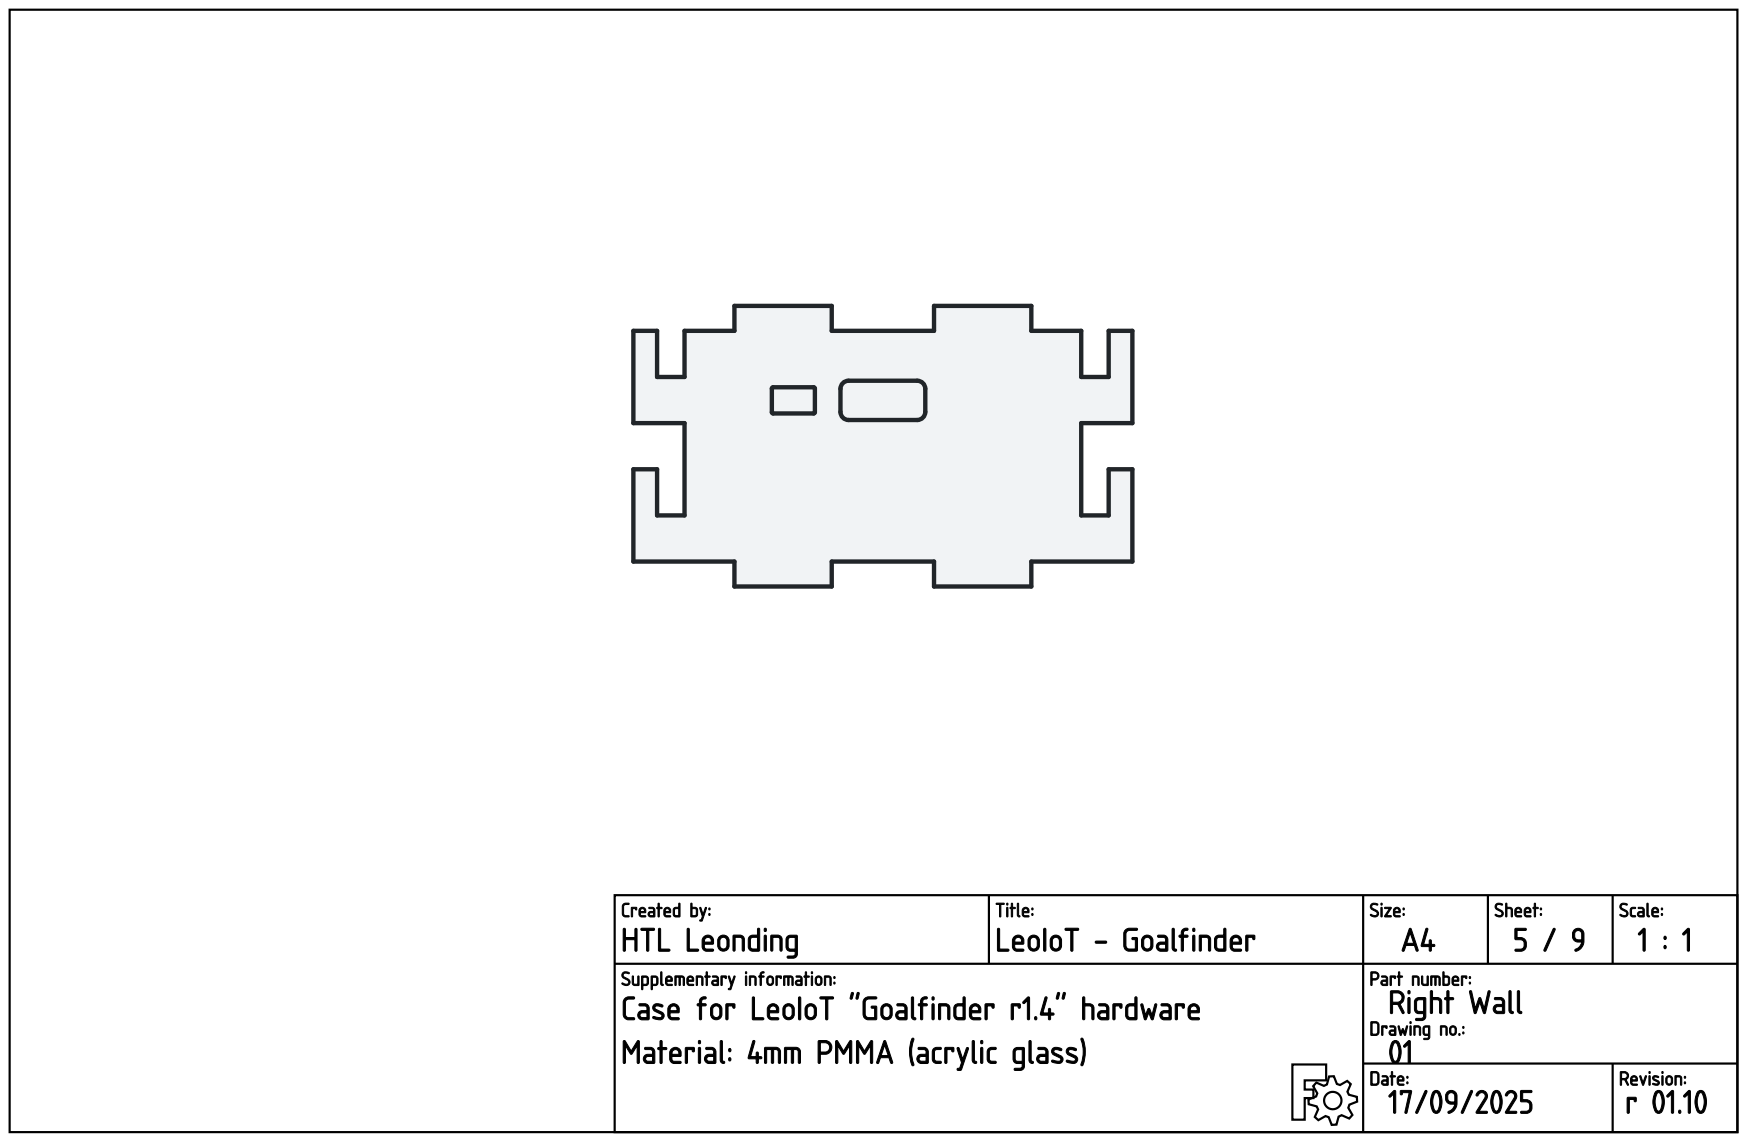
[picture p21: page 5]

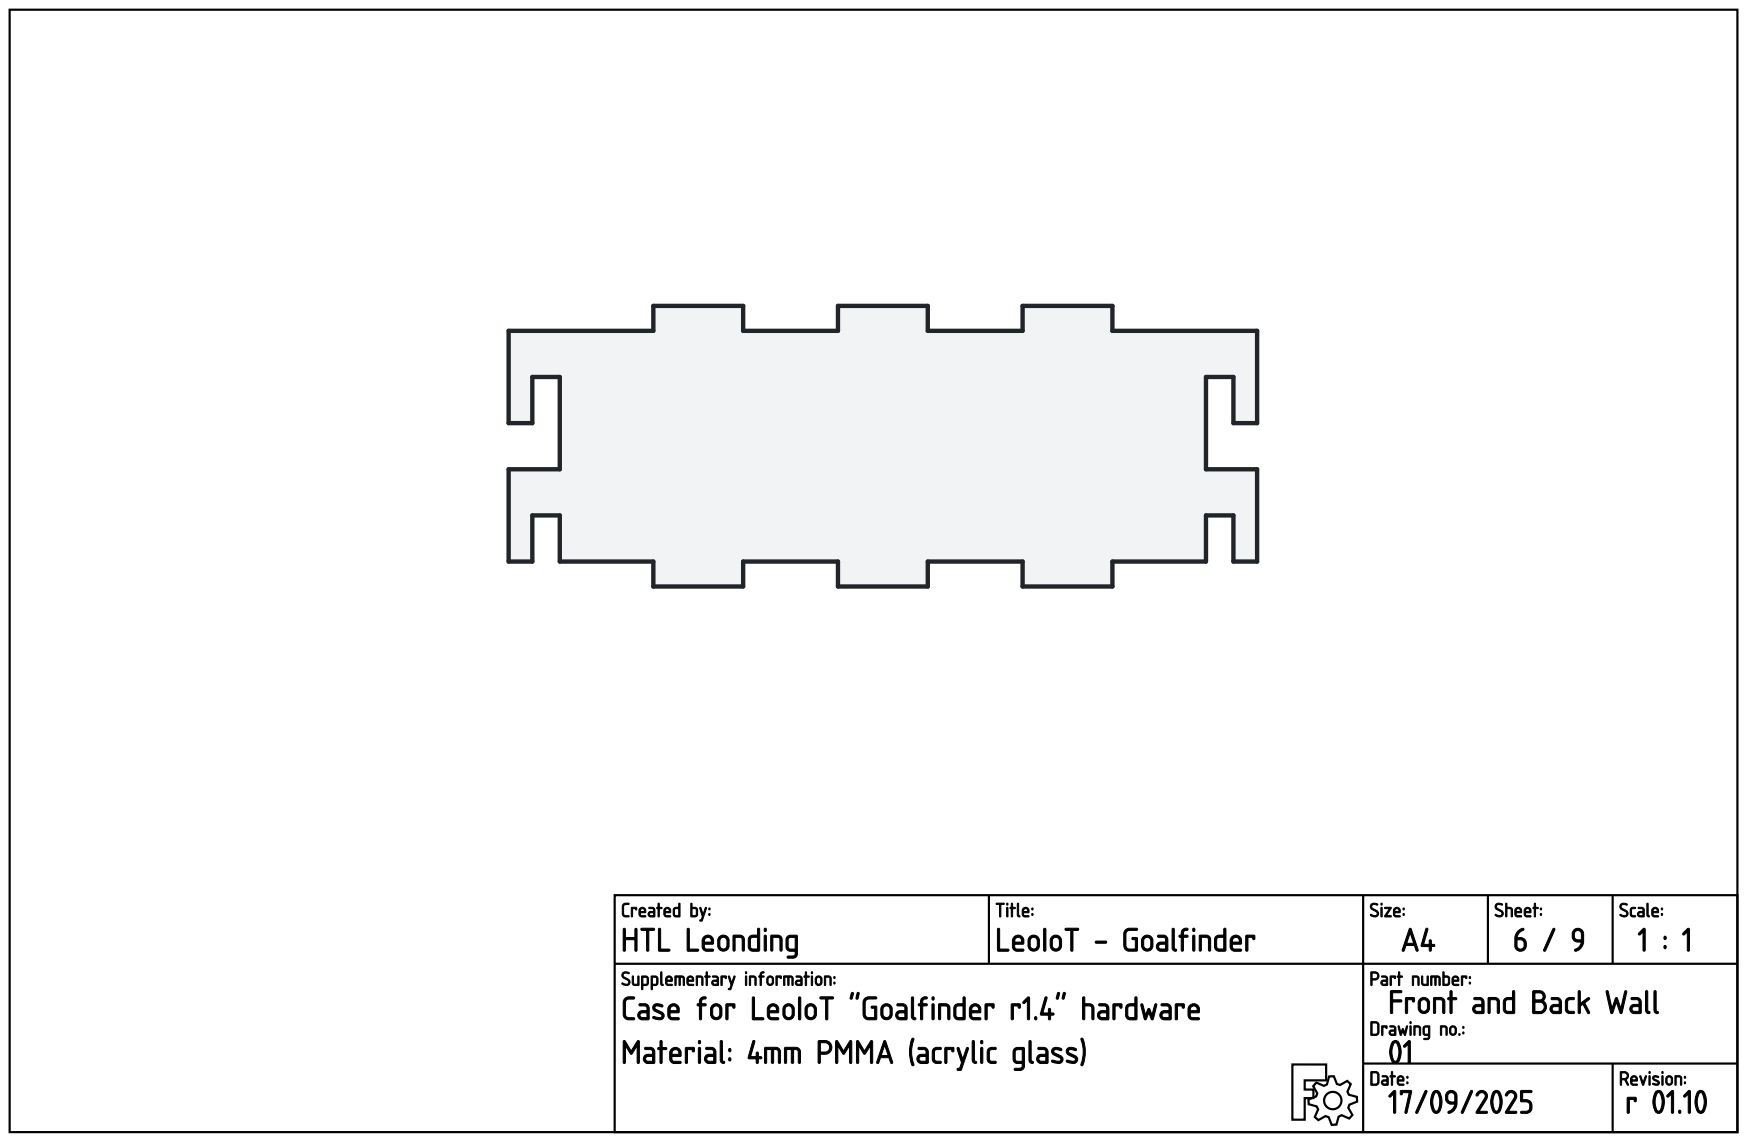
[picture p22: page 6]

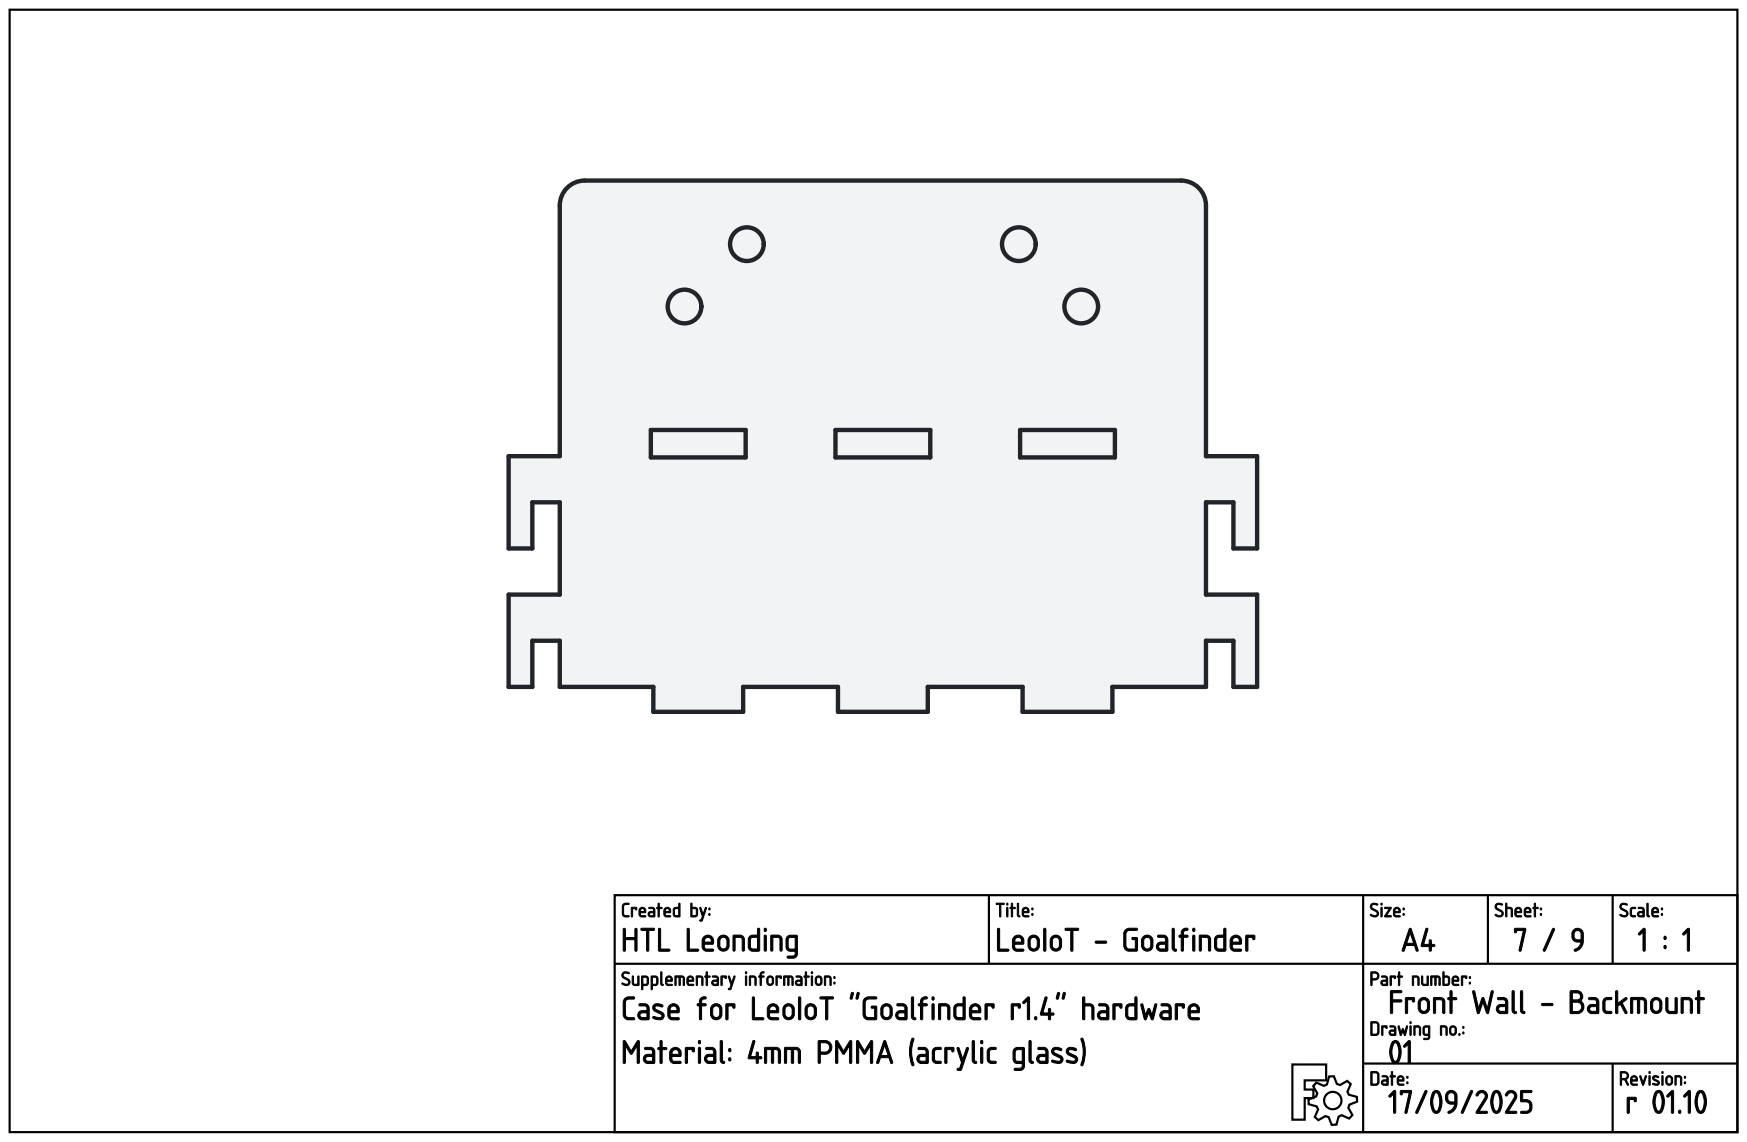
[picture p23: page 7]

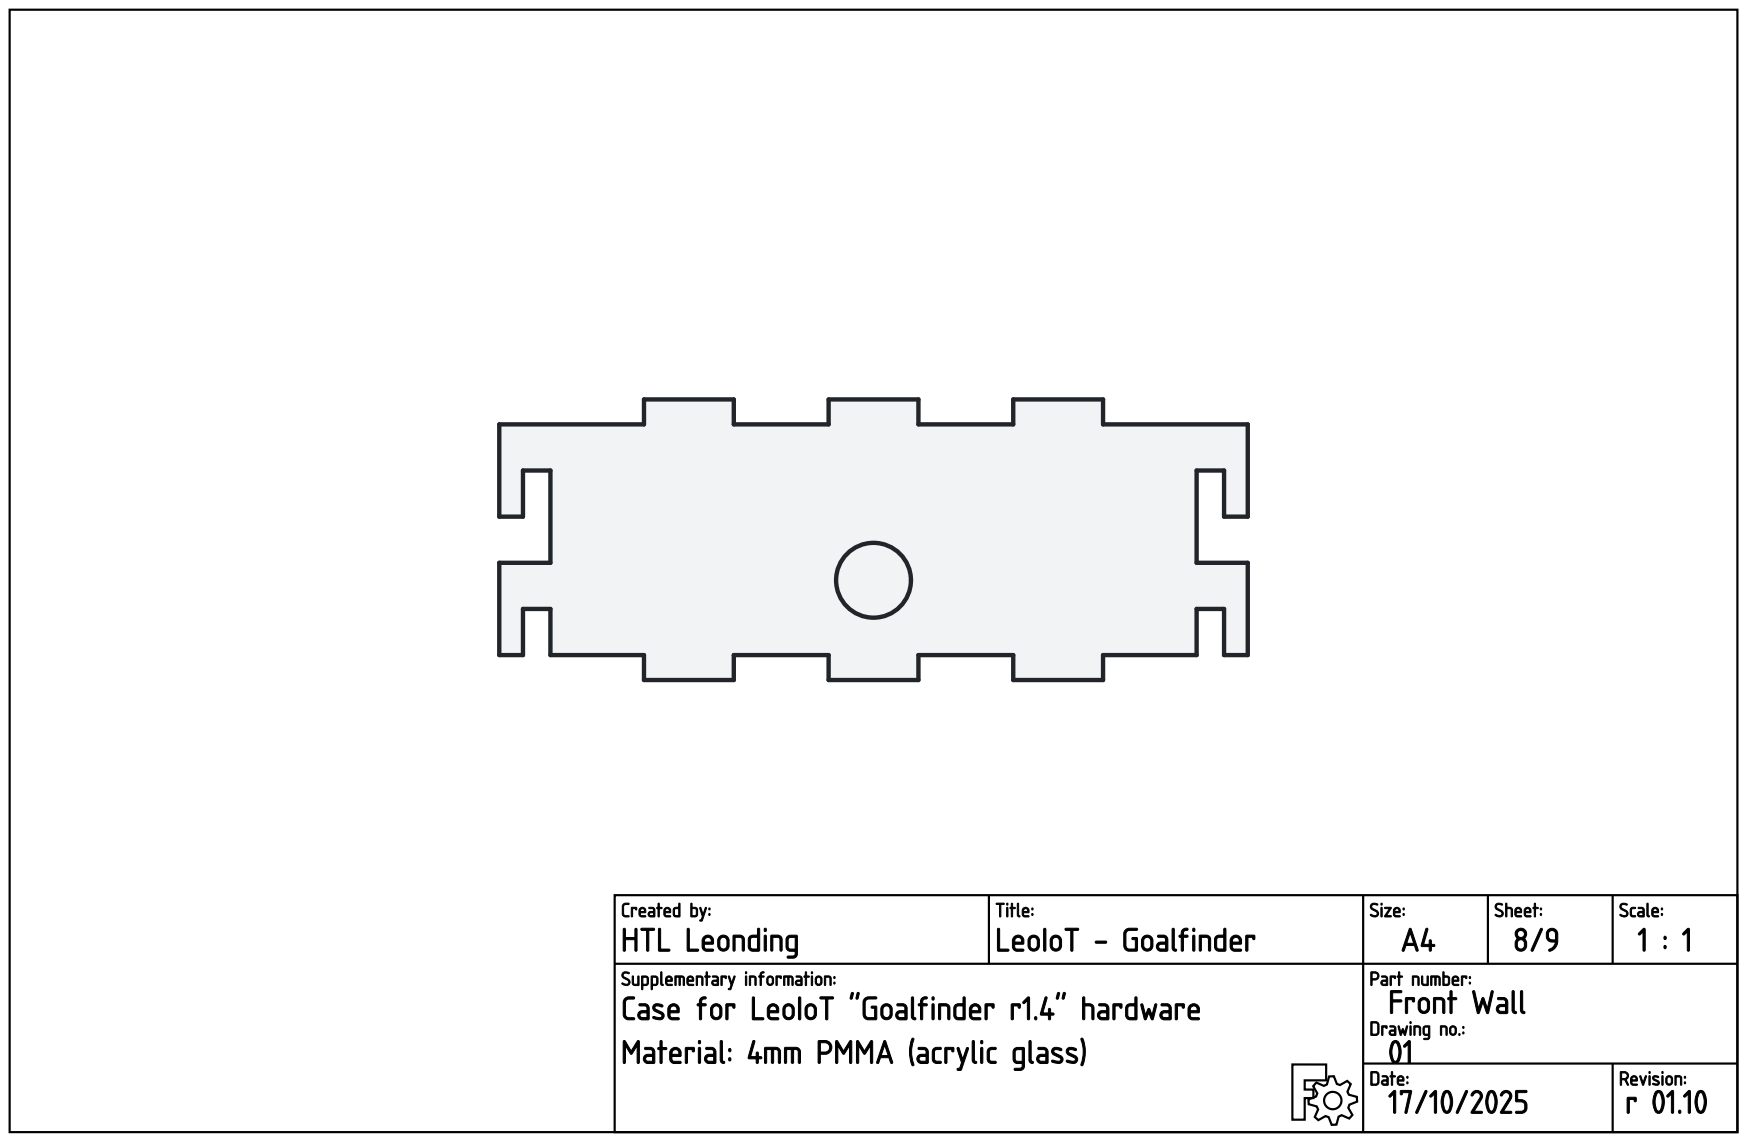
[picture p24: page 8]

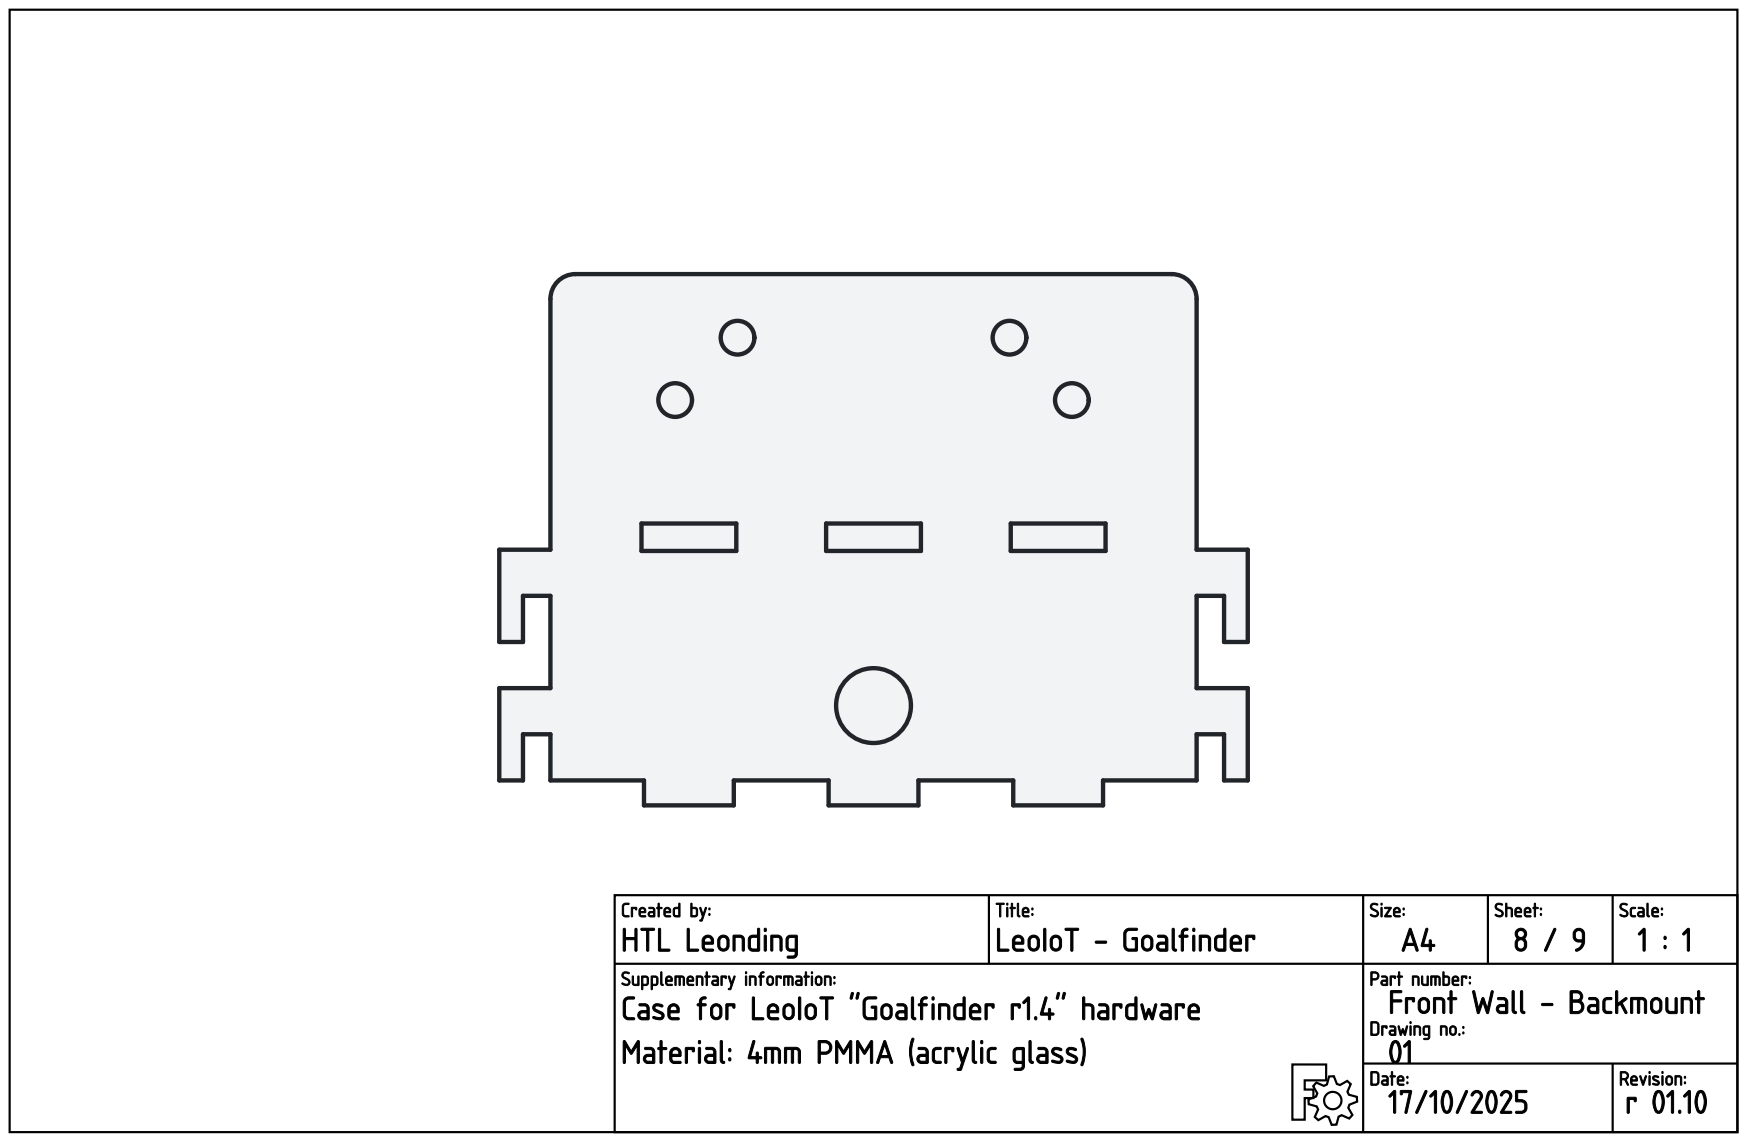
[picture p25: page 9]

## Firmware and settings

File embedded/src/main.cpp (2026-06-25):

/*
 * ===============================================================================
 * (c) HTBLA Leonding 2024 - 2026
 * - - - - - - - - - - - - - - - - - - - - - - - - - - - - - - - - - - - - - - - -
 * Licensed under MIT License.
 *
 * Unless required by applicable law or agreed to in writing, software
 * distributed under the License is distributed on an "AS IS" BASIS,
 * WITHOUT WARRANTIES OR CONDITIONS OF ANY KIND, either express or implied.
 * See the License for the specific language governing permissions and
 * limitations under the license.
 * - - - - - - - - - - - - - - - - - - - - - - - - - - - - - - - - - - - - - - - -
 * All trademarks used in this document are property of their respective owners.
 * ===============================================================================
 */

#include <GoalfinderApp.h>
#include "soc/soc.h"           // Disable brownout problems
#include "soc/rtc_cntl_reg.h"  // Disable brownout problems

void setup() 
{
    WRITE_PERI_REG(RTC_CNTL_BROWN_OUT_REG, 0); //disable brownout detector
    GoalFinderApp::GetInstance()->Init();
}

void loop() 
{
    GoalFinderApp::GetInstance()->Process();
}

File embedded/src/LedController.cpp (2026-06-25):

/*
 * ===============================================================================
 * (c) HTBLA Leonding 2024 - 2026
 * - - - - - - - - - - - - - - - - - - - - - - - - - - - - - - - - - - - - - - - -
 * Licensed under MIT License.
 *
 * Unless required by applicable law or agreed to in writing, software
 * distributed under the License is distributed on an "AS IS" BASIS,
 * WITHOUT WARRANTIES OR CONDITIONS OF ANY KIND, either express or implied.
 * See the License for the specific language governing permissions and
 * limitations under the license.
 * - - - - - - - - - - - - - - - - - - - - - - - - - - - - - - - - - - - - - - - -
 * All trademarks used in this document are property of their respective owners.
 * ===============================================================================
 */

#include "LedController.h"
#include <HardwareSerial.h>
#include <esp32-hal.h>
#include <math.h>
#include "util/Logger.h"

namespace {
constexpr uint32_t defaultFrequency = 5000;
constexpr uint8_t defaultResolution = 12;
constexpr uint16_t maxPwmDuty = (1U << defaultResolution) - 1U;
constexpr unsigned long fadeCycleDurationMs = 1600;
constexpr float tau = 6.28318530718f;
}

LedController::LedController(int ledPin, int ledChannel) 
    : mode(LedMode::Standard), channel(ledChannel), lastStepTimeMs(0), lastAppliedDuty(0),
      _eventActive(false), _eventType(EventEffect::None), _savedMode(LedMode::Standard),
      _eventPhase(0), _eventStartTime(0), _eventBaseDuty(0),
      _eventFlashCount(0), _eventFlashOnMs(0), _eventFlashOffMs(0),
      _eventFadeDurationMs(0), _eventBreatheCycleMs(0), _eventBreatheMaxFraction(0.0f)
{
    ledcSetup(channel, defaultFrequency, defaultResolution);
    ledcAttachPin(ledPin, channel);
    ledcWrite(channel, 0);
}

LedController::~LedController() {}

void LedController::SetMode(LedMode mode)
{
    if (this->mode != mode) {
        if (_eventActive) {
            ClearEvent();
        }
        this->mode = mode;
        lastStepTimeMs = 0;
        lastAppliedDuty = 0xFFFF;
        Logger::Log("LedController", Logger::LogLevel::OK, "%4.3f: LED mode set to '%d'", millis() / 1000.0, this->mode);
    }
}

LedMode LedController::GetMode()
{
    return mode;
}

void LedController::ClearEvent()
{
    _eventActive = false;
    _eventType = EventEffect::None;
    mode = _savedMode;
    _eventPhase = 0;
    _eventStartTime = 0;
    lastStepTimeMs = 0;
    lastAppliedDuty = 0xFFFF;
}

void LedController::OnHit()
{
    if (mode == LedMode::Off) return;

    _savedMode = mode;
    _eventActive = true;
    _eventType = EventEffect::Hit;
    _eventPhase = 0;
    _eventStartTime = millis();
    _eventBaseDuty = maxPwmDuty;
    lastStepTimeMs = 0;
    lastAppliedDuty = 0xFFFF;

    switch (mode) {
        case LedMode::Fade:
            _eventFlashCount = 4;
            _eventFlashOnMs = 200;
            _eventFlashOffMs = 200;
            break;
        case LedMode::Flash:
            _eventFlashCount = 5;
            _eventFlashOnMs = 50;
            _eventFlashOffMs = 50;
            break;
        case LedMode::Turbo:
            _eventFlashCount = 1;
            _eventFlashOnMs = 600;
            _eventFlashOffMs = 0;
            break;
        default:
            _eventFlashCount = 6;
            _eventFlashOnMs = 80;
            _eventFlashOffMs = 80;
            break;
    }
}

void LedController::OnMiss()
{
    if (mode == LedMode::Off) return;

    _savedMode = mode;
    _eventActive = true;
    _eventType = EventEffect::Miss;
    _eventPhase = 0;
    _eventStartTime = millis();
    _eventBaseDuty = maxPwmDuty;
    lastStepTimeMs = 0;
    lastAppliedDuty = 0xFFFF;

    switch (mode) {
        case LedMode::Fade:
            _eventFadeDurationMs = 400;
            break;
        case LedMode::Flash:
            _eventFadeDurationMs = 100;
            break;
        case LedMode::Turbo:
            _eventFadeDurationMs = 800;
            break;
        default:
            _eventFadeDurationMs = 900;
            break;
    }
}

void LedController::OnShotDetected()
{
    if (mode == LedMode::Off) return;

    if (!_eventActive || _eventType != EventEffect::Shot) {
        _savedMode = mode;
        _eventActive = true;
        _eventType = EventEffect::Shot;
        _eventPhase = 0;
        _eventStartTime = millis();
        _eventBaseDuty = maxPwmDuty;
        lastStepTimeMs = 0;
        lastAppliedDuty = 0xFFFF;

        switch (mode) {
            case LedMode::Fade:
                _eventBreatheCycleMs = 800;
                _eventBreatheMaxFraction = 1.0f;
                break;
            case LedMode::Flash:
                _eventBreatheCycleMs = 1400;
                _eventBreatheMaxFraction = 0.7f;
                break;
            case LedMode::Turbo:
                _eventBreatheCycleMs = 1600;
                _eventBreatheMaxFraction = 0.6f;
                break;
            default:
                _eventBreatheCycleMs = 1200;
                _eventBreatheMaxFraction = 0.5f;
                break;
        }
    }
}

void LedController::Loop() 
{
    if (_eventActive) {
        if (_eventType == EventEffect::Hit) {
            RenderHitFlash();
        } else if (_eventType == EventEffect::Miss) {
            RenderMissFade();
        } else if (_eventType == EventEffect::Shot) {
            RenderShotBreathing();
        }
    } else {
        if(mode == LedMode::Standard)
        {
            RenderPermanentStep(maxPwmDuty);
        }
        else if(mode == LedMode::Fade)
        {
            RenderFadeStep();
        }
        else if(mode == LedMode::Flash) 
        {
            RenderFlashStep();
        }
        else if (mode == LedMode::Turbo) 
        {
            RenderTurboStep();
        }
        else 
        {
            RenderPermanentStep(0);
        }
    }
}

uint16_t LedController::ScaleBrightness(uint16_t value) {
    uint16_t scaled = 0;
    if (value != 0) {
        int ledBrightness = Settings::GetInstance()->GetLedBrightness();
        ledBrightness = max(min(ledBrightness, 100), 0);
        scaled = (uint16_t)roundf(value * ledBrightness / 100.0f);
    }
    return scaled;
}

void LedController::RenderPermanentStep(uint16_t brightness) {
    uint16_t scaled = ScaleBrightness(brightness);
    if (scaled != lastAppliedDuty) {
        lastAppliedDuty = scaled;
        ledcWrite(channel, lastAppliedDuty);
    }
}
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

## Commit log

2025-12-24 Progress on restructuring project layout+
    [Distance-16.4.stl, Distance-19.stl, JST-SYP_Female.step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]
2025-12-24 Sorted .stl files
    [Distance-16.4.stl, Distance-19.stl, bracket-top-left.stl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]
2025-12-25 Reworked blueprint/ structure
    [bracket-top-left.stl, bracket-top-right.stl, powerbank-bracket.stl]
2025-12-25 Reworked Schematic to use MPU6050
2026-02-08 Fixed mutex for audio playback
    [GoalfinderApp.cpp]
2026-02-09 added original assembly photos
2026-02-09 added high_res and low_res assembly photos
2026-02-10 Add captive portal for auto browser open on WiFi connect\n\nAdd DNS server that redirects all domain lookups to the AP IP, plus\ncaptive portal detection endpoints for Android, iOS/macOS, Windows,\na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
2026-02-12 Implement scanning for other GoalFinder devices #77
2026-02-12 Fixed Hit/Miss buttons not working properly
2026-02-12 Fixed Zeitspiel-Challange: Buttons
2026-02-12 Added/Fixed reset device to factory settings
2026-02-14 Improved core binding for crutial tasks #3
    [GoalfinderApp.cpp]
2026-02-14 Improved styling unity for LED settings #72
2026-02-14 Added proper clamping of values for settings #72
2026-02-14 Added device side auth handling #103
2026-02-19 Move unused abstraction layer for device / LED settings
2026-02-19 Added device side settings for #98 & #126
2026-02-19 Implement led brightness in LedController #98
2026-02-20 Fixed Settings Instance issue and fixed saving of distance only hit detection #126
    [LedController.cpp]
2026-02-22 Applied fix for #140
    [GoalfinderApp.cpp]
2026-02-22 Moved device connection settings into own view and added placeholder restart modal
2026-02-24 Fixed audio selection #147
    [GoalfinderApp.cpp]
2026-02-24 Fixed looping in GoalfinderApp & added missing sound paths in array #147
    [GoalfinderApp.cpp]
2026-02-24 Applied further fixes to make detection distance better setable #148
    [GoalfinderApp.cpp]
2026-02-27 Added working example for testing accelerometer shot detection #109
2026-03-03 Reworked lib for SW420
    [GoalfinderApp.cpp]
2026-03-17 Removed ununnecessary assets from repository #122
    [Goalfinder-B_Adhesive.gbr, Goalfinder-B_Cu.gbr, Goalfinder-B_Mask.gbr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]
2026-03-20 Added PCB Component 3D models
    [Goalfinder.kicad_pcb, MAX98357A_I2S.STEP, VL53L0X_TOF.step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]
2026-03-28 Added GoalFinder printing projects
    [goalfinder.3mf]
2026-04-02 Reduced interference of web app loading on audio #167
    [GoalfinderApp.cpp]
2026-04-02 Fixed web socket not opening on certain devices #170
    [GoalfinderApp.cpp]
2026-04-02 Fixed inconsitent LED fading animation #168
    [LedController.cpp]
2026-04-04 Added device side settings for #157 & #172
2026-04-04 Added device side settings for #153
2026-04-04 Added device side handling of DNS disabling #173
2026-04-06 Added proper clamping of number of audios per event #157
2026-04-06 Improved web app side LED settings #157
2026-04-06 Made flash and turbo LED timing connected to metronome timing #157
2026-04-06 Added simplified controls for sensor sensitivity #157
2026-04-10 fix: vulnerability #185
    [goalfinder.3mf]
2026-04-17 revert: undo recent changes made on the wrong branch
    [GoalfinderApp.cpp]
2026-04-19 add: AGENTS.md file and agent skills & improve handling of device password entering
2026-04-21 fix: showing device password when advanced settings are disabled
2026-04-21 fix: intial hotfix for #194
    [GoalfinderApp.cpp]
2026-04-28 remove: dubplicate apply button for enterprise network password #226
2026-05-03 refactor: device name input #193
2026-05-03 remove: apply button for personal auth external networks
2026-05-06 fix: include path for logger
    [Logger.cpp]
2026-06-07 fix: not recognzing valid readings for VL53L0X #212
    [GoalfinderApp.cpp]
2026-06-07 add: initial rework of the hit detection logic #212 #213
    [GoalfinderApp.cpp]
2026-06-17 fix: css and redirect error
    [GoalfinderApp.cpp]
2026-06-17 add: basic LED feedback #149
2026-06-24 improve: general hit detection
    [goalfinder-1.10.FCStd]
2026-06-24 fix: inverted sensitivity setting #240
    [GoalfinderApp.cpp]
2026-06-24 fix: reliability when reading hit right after shot event
    [GoalfinderApp.cpp]
2026-06-24 replace: old text based header buttons with icons and add play pause switching to all affected icons
2026-06-24 fix: led feedback bugs & add: LED mode specific LED event animations #149
    [GoalfinderApp.cpp, LedController.cpp]
2026-06-30 update: inital PCB design version to 0.1.5
    [Goalfinder-B_Adhesive.gbr, Goalfinder-B_Cu.gbr, Goalfinder-B_Mask.gbr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]
2026-06-30 remove: old GoalFinder PCB export
    [Goalfinder-B_Adhesive.gbr, Goalfinder-B_Cu.gbr, Goalfinder-B_Mask.gbr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]
2026-06-30 move: entire old GoalFinder blueprint files #144
    [Goalfinder.kicad_pcb, Goalfinder.kicad_sch, goalfinder-1.10.FCStd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]
2026-06-30 add: KiCAD files for v1.0.0 project #144 #145
    [goalfinder-tof-module.kicad_pcb, goalfinder-tof-module.kicad_sch, goalfinder.kicad_pcb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]
2026-06-30 refactor: PCB files into speerate tof module project and main device project #144
    [goalfinder-tof-module.kicad_pcb, goalfinder-tof-module.kicad_sch, goalfinder.kicad_pcb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]
